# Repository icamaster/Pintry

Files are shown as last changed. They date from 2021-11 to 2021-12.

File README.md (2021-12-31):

## Introduction
The Pintry X2 is a two bay NAS (Network Attached Storage) based on the Raspberry Pi Compute Module 4. It uses the ASMedia AS1061 PCIe to Sata bridge to connect up to 2 drives (3.5'/2.5' HDD or 2.5' SSD) to the SoM running a Linux based OS (Raspberry Pi OS).

## Website
Here is a link for additional information: https://www.cezarchirila.com/projects/pintry-x2.html

## Features
* Supports both CM4 and CM4 lite variants
* 2 x SATA ports with power using ASM1061. It should work with both 2.5' and 3.5' HDDs/SSDs but so far it has only been tested with 2.5' SSDs (Western Digital WDS500G2B0A)
* On/Off switch - Can both wake up the CM4 or shut it down (see Device Tree Overlay section) 
* 2 x Fan headers (PWM pin connected, Tach pin unconnected)
* 12V Input Power (max 5A, required for 3.5' drives). 
* USB 2.0 Host port for connecting USB devices and a microUSB Device port for updating the eMMC on CM4. 
* Expander header for access to various GPIO

## Names have a meaning
Pi + Pantry = Pintry

## Device Tree Overlay
Add these changes at the end of the /boot/config.txt to enable specific functionality:
```
# Enable FAN control for FAN0
dtoverlay=gpio-fan,gpiopin=12

# Enable FAN control for FAN1
#dtoverlay=gpio-fan,gpiopin=13

# Enable full functionality of On/Off button
dtoverlay=gpio-shutdown,gpio_pin=21,active_low=0,gpio_pull=off

# Enable UART - UNTESTED
#dtoverlay=uart0,txd0_pin=14,rxd0_pin=15,pin_func=4
#enable_uart=1  
```
Remember to remove the '#' in from of options you want to enable. 

## Kernel
Previously, to be able to use SATA drives with a CM4 you had to recompile the kernel with added SATA support. See instructions [here](https://github.com/geerlingguy/raspberry-pi-pcie-devices/issues/1#issuecomment-717578358) (credit to [Jeff Geerling](github.com/geerlingguy) for instructions). However, newer kernel versions have SATA support built-in, so you should not have to worry about this.

## Enclosure
The enclosure supports 2.5' drives only. It does not have any mounting features for fans, but there is room for a 60mm fan on the bottom as shown in the images below. It does not need supports for printing. Designed in Fusion 360.

For assembly, you will need the following:
* 4 x M3 brass inserts (D0.46mm, L0.57mm)
* 4 x M3x18mm socket screws - for mounting the drives 
* 4 x M3x25mm socket screws - for mounting the drives
* 4 x M3x35mm socket screws - for joining the two halves of the enclosure

## Thermal management
To keep temperatures under control, I have used a RAM heatsink on the ASM1061 IC and a 60mm fan on the bottom of the enclosure tied to the FAN header and controlled via the 'gpio-fan' overlay. It is mounted in such way that it blows air over both the CM4 and the ASM1061.  

## Release
The current latest release is V1.1. This version has not been tested or manufactured yet, therefore I would suggest double checking it if you plan on bulding it!
All the necessary manufacturing and assembly files are in the 'OutputJob/Version' and 'Enclosure' folders.

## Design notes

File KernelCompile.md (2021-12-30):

# Credits to Jeff Geerling
These instructions have been pulled from https://github.com/geerlingguy

## Install dependencies
sudo apt install -y git bc bison flex libssl-dev make libncurses5-dev

## Clone source
git clone --depth=1 https://github.com/raspberrypi/linux

## Apply default configuration
cd linux
export KERNEL=kernel7l # use kernel8 for 64-bit, or kernel7l for 32-bit
make bcm2711_defconfig

## Customize the .config further with menuconfig
make menuconfig
 Enable the following:
 Device Drivers:
   -> Serial ATA and Parallel ATA drivers (libata)
     -> AHCI SATA support
     -> Marvell SATA support

 Alternatively add the following in .config manually:
 CONFIG_ATA=m
 CONFIG_ATA_VERBOSE_ERROR=y
 CONFIG_SATA_PMP=y
 CONFIG_SATA_AHCI=m
 CONFIG_SATA_MOBILE_LPM_POLICY=0
 CONFIG_ATA_SFF=y
 CONFIG_ATA_BMDMA=y
 CONFIG_SATA_MV=m

nano .config
 (edit CONFIG_LOCALVERSION and add a suffix that helps you identify your build)

## Build the kernel and copy everything into place
make -j4 zImage modules dtbs # 'Image' on 64-bit
sudo make modules_install
sudo cp arch/arm/boot/dts/*.dtb /boot/
sudo cp arch/arm/boot/dts/overlays/*.dtb* /boot/overlays/
sudo cp arch/arm/boot/dts/overlays/README /boot/overlays/
sudo cp arch/arm/boot/zImage /boot/$KERNEL.img

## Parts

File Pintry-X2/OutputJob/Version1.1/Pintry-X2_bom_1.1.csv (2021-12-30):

Component | Description | References | Value | Quantity Per PCB | Manufacturer | Part Number | Voltage Rating | Type | fit_field
1 | Unpolarized capacitor, small symbol | C18 | 15pF | 1 |  |  | 50V | NPO
2 | Unpolarized capacitor, small symbol | C19 C20 C45 C46 C47 C48 C51 C52 C53 C54 | 0.01uF | 10 |  |  | 25V | X7R
3 | Unpolarized capacitor, small symbol | C2 C3 C4 C7 C9 C11 C12 C13 C15 C23 C27 C28 C30 C31 C32 C33 C34 C35 C36 C37 C38 C39 C40 C41 C42 C43 C44 C57 C60 C65 | 0.1uF | 30 |  |  | 25V | X7R
4 | Unpolarized capacitor, small symbol | C61 | 1uF | 1 |  |  | 25V | X7R
5 | Unpolarized capacitor, small symbol | C1 C5 C14 C16 C17 C24 C29 C67 C68 | 10uF | 9 |  |  | 10V | X7R
6 | Unpolarized capacitor, small symbol | C58 | 22uF | 1 | Samsung | CL21A226MOQNNNE | 16V | X7R
7 | Unpolarized capacitor, small symbol | C6 C62 C63 C64 | 22uF | 4 | Murata | GRM21BR61A226ME51L | 16V | X7R
8 | Polarized capacitor, small symbol | C8 C10 C49 C50 C55 C56 C66 | 865080443007 | 7 | Wurth | 865080443007
9 | Unpolarized capacitor, small symbol | C59 | TBD | 1 |  |  | 25V | X7R | dnf
10 | LED Orange Clear | D9 D17 | APA2107SECK | 2 | Kingbright | APA2107SECK/J4-PRV
11 | LED Orange Clear | D8 | APA2107SECK | 1 | Kingbright | APA2107SECK/J4-PRV
12 | 300mW Zener Diode, SOD-323 | D24 D26 | BZX384-B13 | 2 | Nexperia | BZX384-B13,115
13 | Diode TVS 3V3 | D3 D4 D5 D6 D10 D11 D12 | D3V3M1U259-7 | 7 | Diodes | D3V3M1U2S9-7
14 | Diode | D13 D14 D21 D23 D25 | DF2S16FS,L3M | 5 | Toshiba | DF2S16FS,L3M
15 | Diode | D1 D2 D7 D15 D16 D20 D22 | DF2S6.2FS,L3M | 7 | Toshiba | DF2S6.2FS,L3M
16 | Ferrite bead, small symbol | FB1 FB2 FB3 FB4 FB5 FB6 | MPZ1608S101ATAH0 | 6 | TDK | MPZ1608S101ATAH0
17 | Common mode choke, 300mA, 300VAC, 22mH, 1.3 ohm, RN-102 | FL1 | DLW5BTM101SQ2L | 1 | Murata | DLW5BTM101SQ2L
18 | SATA Backplane Receptacle Vertical SMT | J9 J10 | 1735284-3 | 2 | TE Connectivity | 1735284-3
19 | DC Barrel Jack with an internal switch | J11 | 54-00131 | 1 | Tensility | 54-00131
20 | Micro SD Card Socket with card detection pins | J4 | DM3D-SF | 1 | Hirose | DM3D-SF
21 | Generic connector, double row, 02x05, odd/even pin numbering scheme (row 1 odd numbers, row 2 even numbers), script generated (kicad-library-utils/schlib/autogen/connector/) | J6 | Expansion | 1 | Adam Tech | 2PH2-10-UA
22 | Generic connector, single row, 01x04, script generated (kicad-library-utils/schlib/autogen/connector/) | J7 J8 | Fan | 2 | Molex | 47053-1000
23 | LAN Transformer Jack, RJ45, 10/100/1000 BaseT | J3 | JD0-0001NL | 1 | Pulse | JD0-0001NL
24 | Generic connector, single row, 01x03, script generated (kicad-library-utils/schlib/autogen/connector/) | J5 | UART | 1 | Adam Tech | PH1-03-UA
25 | USB Type A connector | J2 | USB_A | 1 | Amphenol ICC | 73725-11A0BLF
26 | USB Micro Type B connector | J1 | USB_B_Micro | 1 | Amphenol ICC | 10103594-0001LF
27 | 4.7µH Shielded Wirewound Inductor 2.6A 35mOhm | L1 | NRS5030T4R7MMGJ | 1 | Taiyo Yuden | NRS5030T4R7MMGJ
28 | 1.2µH Shielded Molded Inductor 10A 12mOhm | L2 | PA4341.122NLT | 1 | Pulse | PA4341.122NLT
29 |  | Module1 | ComputeModule4-CM4 | 1 | Hirose | 2x DF40C-100DS-0.4V
30 | PNP transistor, base/emitter/collector | Q6 | BC857BW | 1 | Nexperia | BC857BW,135
31 | N-MOSFET transistor, gate/source/drain | Q1 Q2 Q3 | BSS138PW | 3 | Nexperia | BSS138PW,115
32 | -12A Id, -30V Vds, P-Channel MOSFET | Q5 | SIA483DJ | 1 | Vishay | SIA483DJ-T1-GE3
33 | -12A Id, -30V Vds, P-Channel MOSFET | Q7 | SIA483DJ | 1 | Vishay | SIA483DJ-T1-GE3
34 | Resistor, US symbol | R33 R34 | 0R | 2 |  |  |  |  | dnf
35 | Resistor, US symbol | R3 R4 | 470R | 2
36 | Resistor, US symbol | R1 R6 R14 R19 R20 | 1K | 5
37 | Resistor, US symbol | R2 R5 R7 R8 R11 R16 R17 R18 R21 R27 R28 R32 | 4K7 | 12 |  |  |  |  | dnf
38 | Resistor, US symbol | R12 R13 | 12K1 | 2
39 | Resistor, US symbol | R30 | 30K1 | 1
40 | Resistor, US symbol | R9 R10 R15 R22 R23 R24 R25 R26 R31 R35 R36 | 100K | 11 |  |  |  |  | dnf
41 | Resistor, US symbol | R29 | 221K | 1
42 | Push button switch, generic, two pins | SW1 | SW_Push | 1 | TE Connectivity | 1-1825027-4
43 | Single Buffer Gate Tri-State, Low-Voltage CMOS | U4 | 74AHCT1G126 | 1 | Diodes | 74AHCT1G126SE-7
44 | 4.5V TO 18V INPUT, 6A SYNCHRONOUS BUCK CONVERTER | U13 | AP62600 | 1 | Diodes | AP62600SJ-7
45 | PCI Express 2.0 to 2 x SATA 6Gbps Controller | U7 | ASM1061 | 1 | ASMedia | ASM1061
46 | USB Switch IC 1 Channel 10-MSOP | U14 | FSUSB30MUX | 1 | ON Semiconductor | FSUSB30MUX
47 |  | U15 | MIC2005-0.5LYM5 | 1 | Microchip | MIC2005-0.5LYM5
48 | Single Schmitt Buffer Gate, Low-Voltage CMOS | U3 | SN74LVC1G17 | 1 | Texas Instruments | SN74LVC1G17DBVR
49 | 8-Mbit, 2.7 to 3.6V, SPI Flash Memory, SOIC-8 | U10 | SST25VF512A | 1 | Microchip | SST25VF512A-33-4I-SAE-T
50 | 4-Channel ESD Protection for Super-Speed USB 3.0 Interface, USON-10 | U1 U2 U5 U6 U11 U12 | TPD4EUSB30 | 6 | Texas Instruments | TPD4EUSB30DQAR
51 | Four pin crystal, GND on pins 2 and 4 | Y1 | ECS-200-12-33-AGN-TR | 1 | ECS | ECS-200-12-33-AGN-TR
Component Groups: | 51
Component Count: | 166
Fitted Components: | 166
Number of PCBs: | 1
Total components: | 166
Schematic Version: | 1.1
Schematic Date:
PCB Variant: | default
BoM Date: | 30/12/2021 15:42:43
Schematic Source: | Pintry-X2.kicad_sch
KiCad Version: | Eeschema (6.0.0)

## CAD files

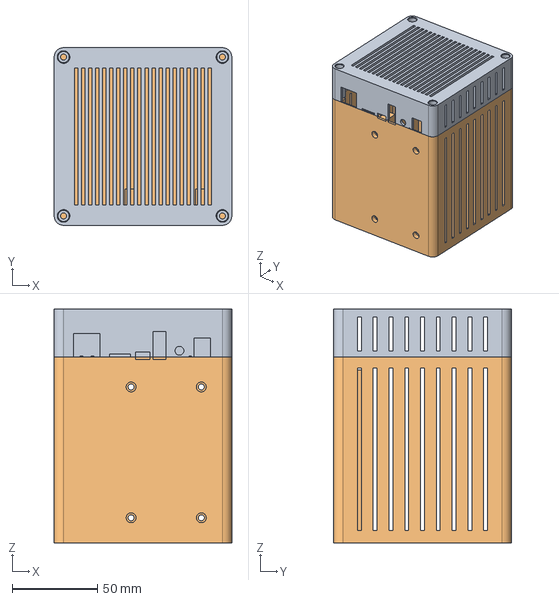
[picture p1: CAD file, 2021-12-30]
Pintry-X2/Enclosure/Pintry-X2_enclosure.step
104.0 x 104.0 x 137.0 mm

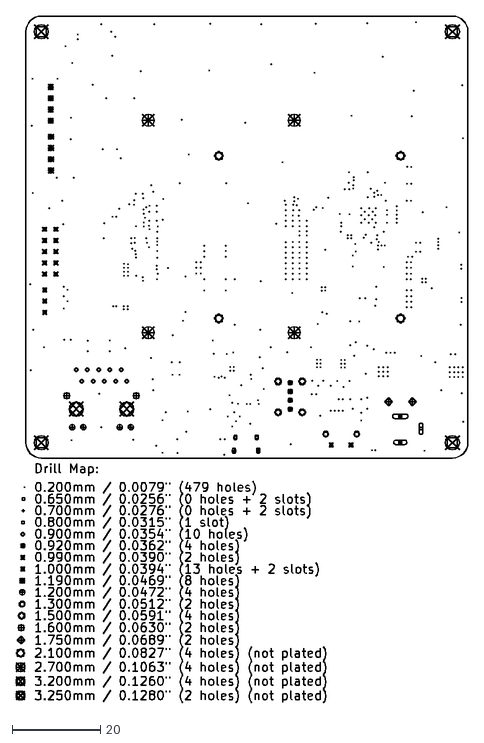
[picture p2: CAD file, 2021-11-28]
Pintry-X2/Pintry-X2-drl_map.dxf
102.2 x 155.4

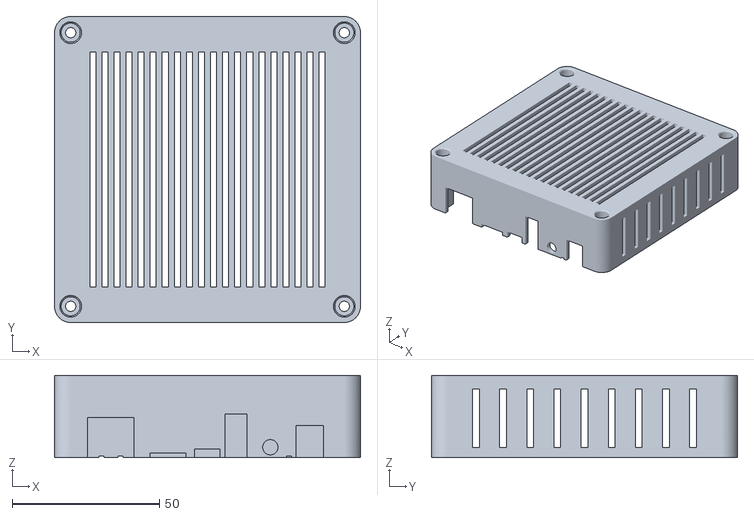
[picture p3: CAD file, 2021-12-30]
Pintry-X2/Enclosure/Bottom.stl
104.0 x 104.0 x 28.0

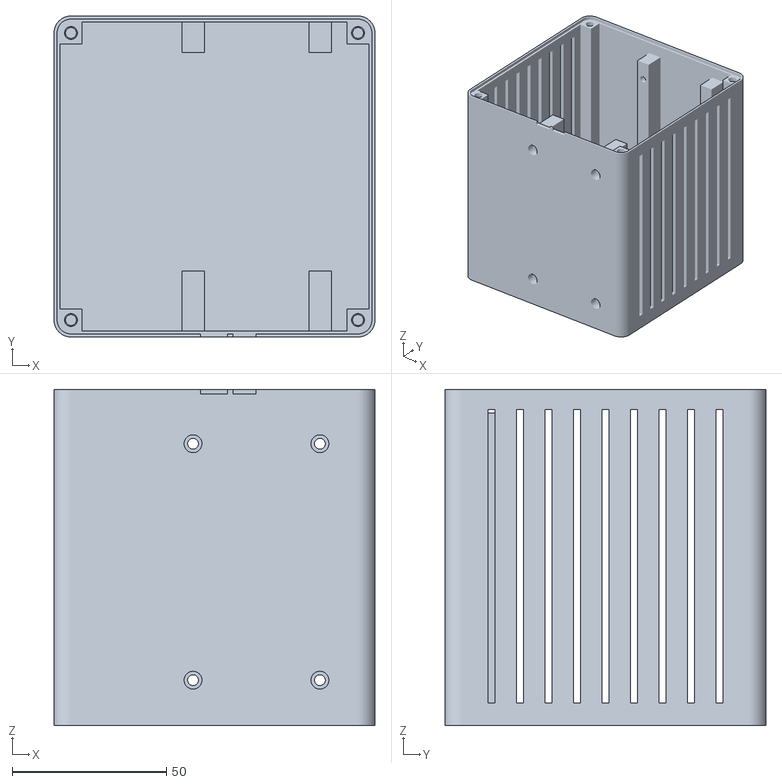
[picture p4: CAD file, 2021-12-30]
Pintry-X2/Enclosure/Top.stl
104.0 x 104.0 x 109.0

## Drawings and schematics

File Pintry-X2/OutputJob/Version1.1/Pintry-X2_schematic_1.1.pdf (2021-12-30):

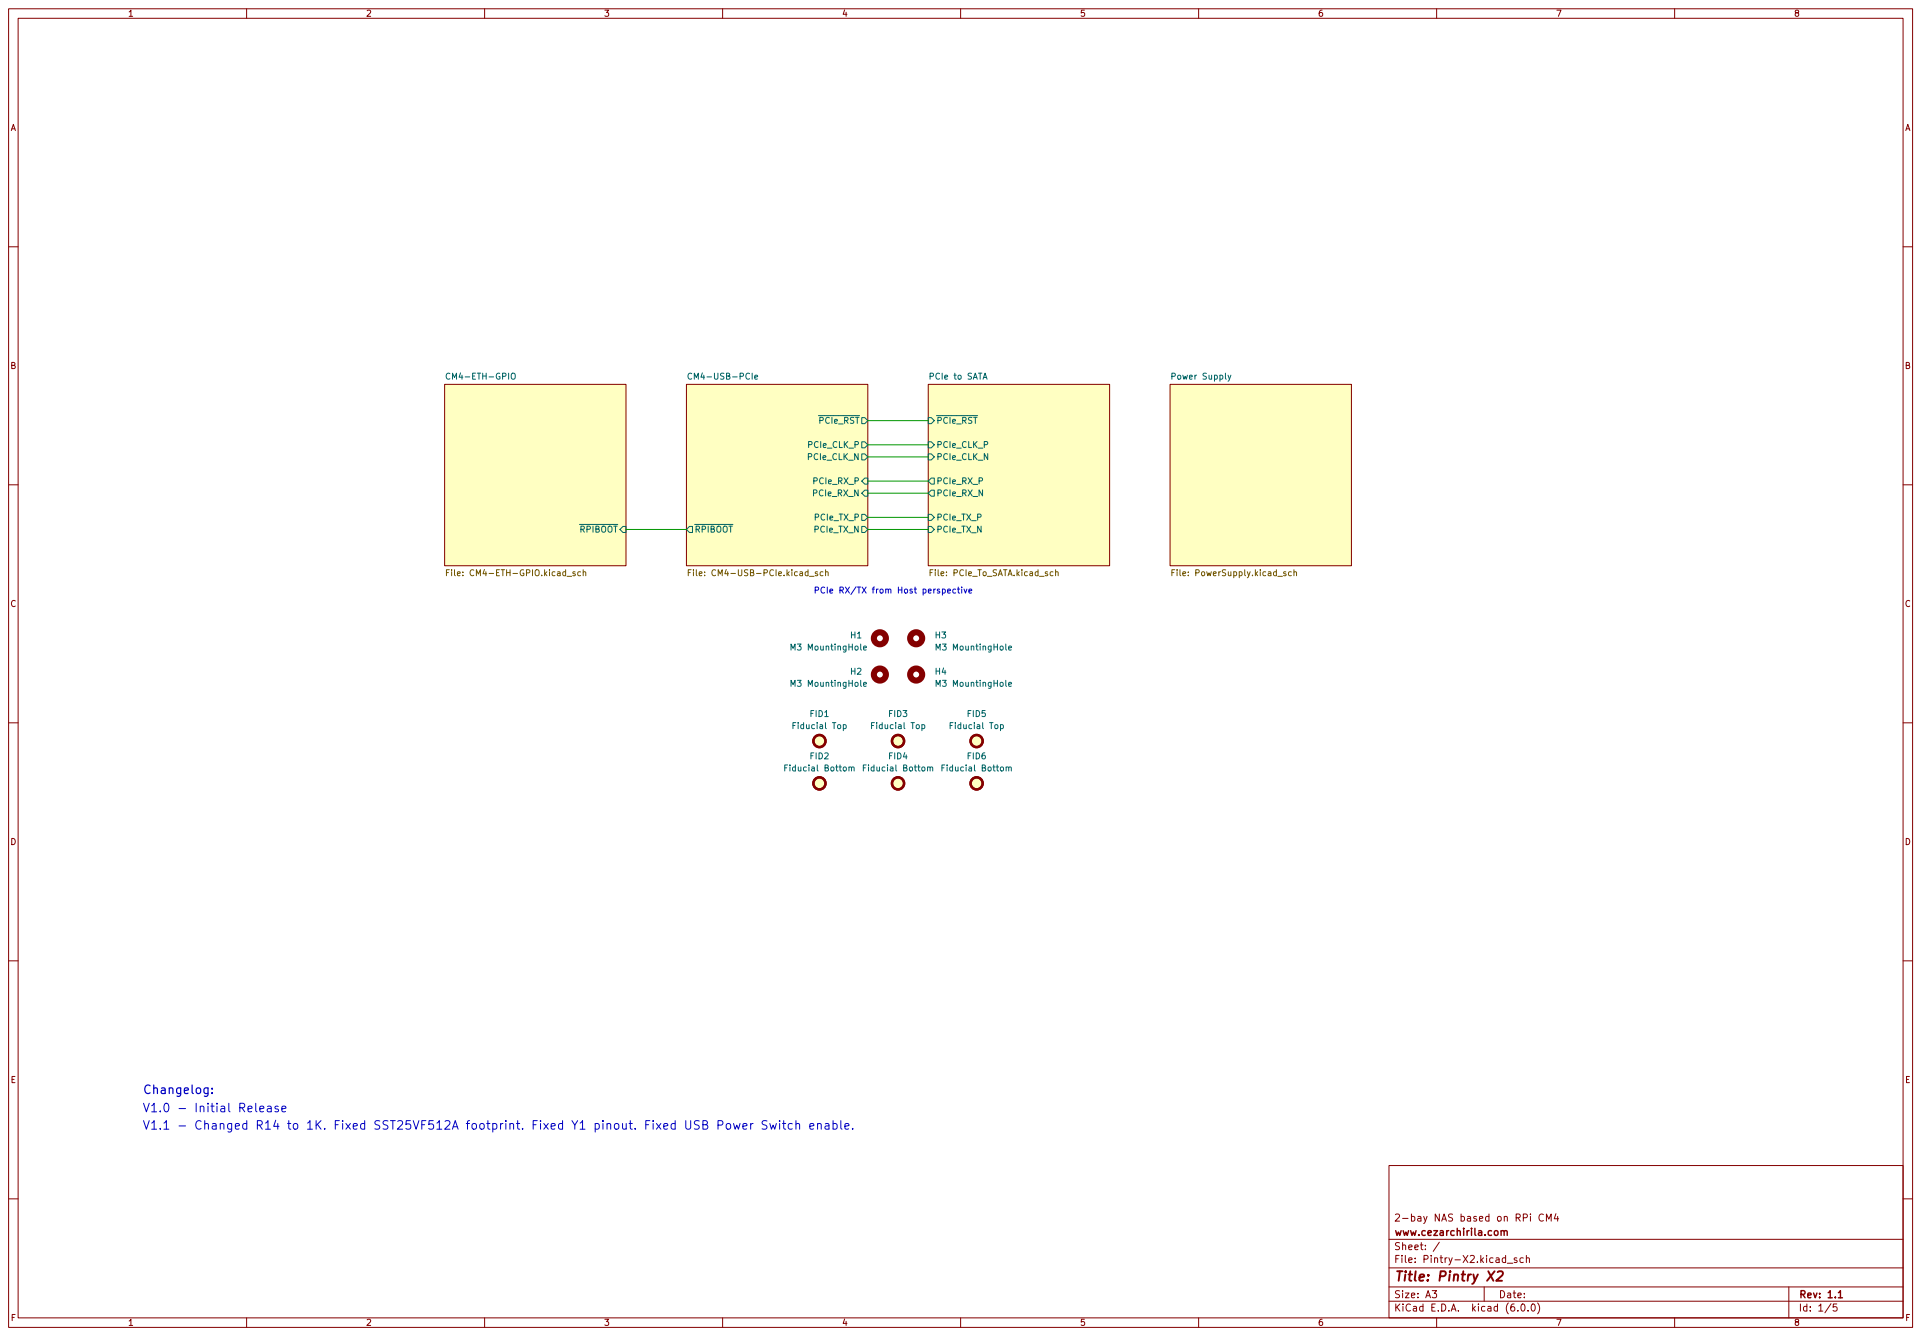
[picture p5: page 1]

File: PCIe_To_SATA.kicad_sch ~{RPIBOOT} CM4-ETH-GPIO

PCIe_TX_P
H3M3 MountingHole H4M3 MountingHole FID6 Fiducial Bottom

PCIe RX/TX from Host perspective

FID5 Fiducial Top FID4 Fiducial Bottom

Changelog:
V1.0 - Initial Release
V1.1 - Changed R14 to 1K. Fixed SST25VF512A footprint. Fixed Y1 pinout. Fixed USB Power Switch enable.

2-bay NAS based on RPi CM4
File: Pintry-X2.kicad_sch Sheet: / www.cezarchirila.com

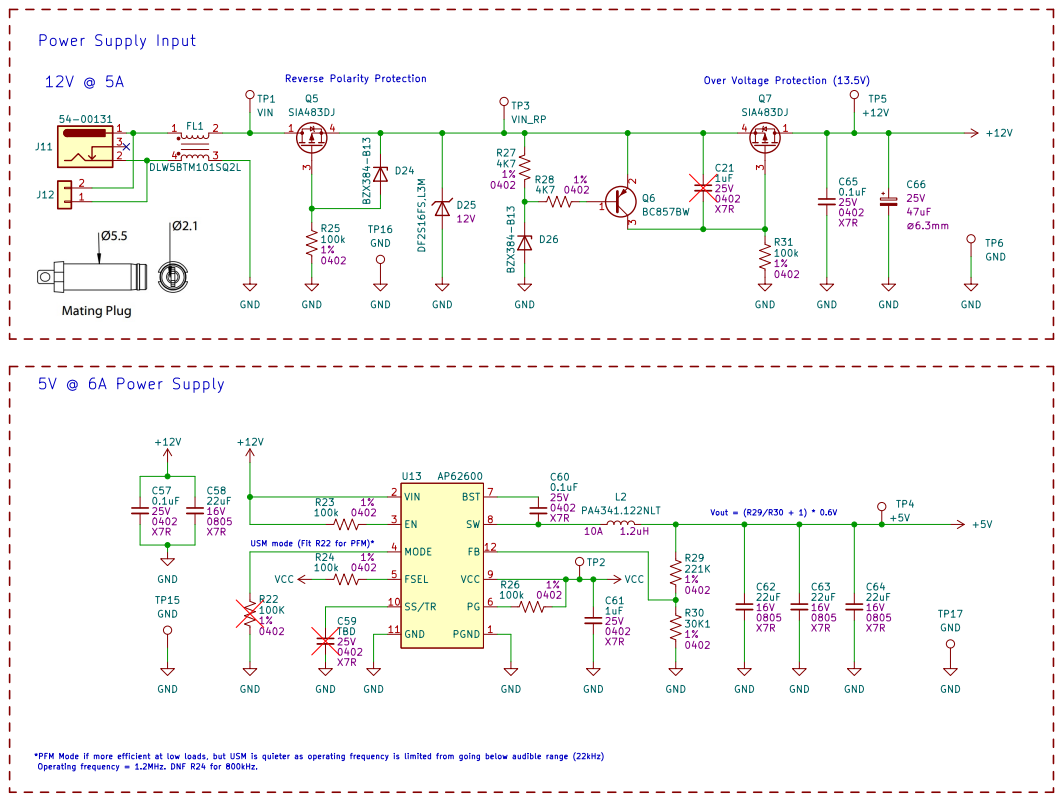
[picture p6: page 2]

*PFM Mode if more efficient at low loads, but USM is quieter as operating frequency is limited from going below audible range (22kHz) Operating frequency = 1.2MHz. DNF R24 for 800kHz.

2-bay NAS based on RPi CM4
Sheet: /Power Supply/ www.cezarchirila.com

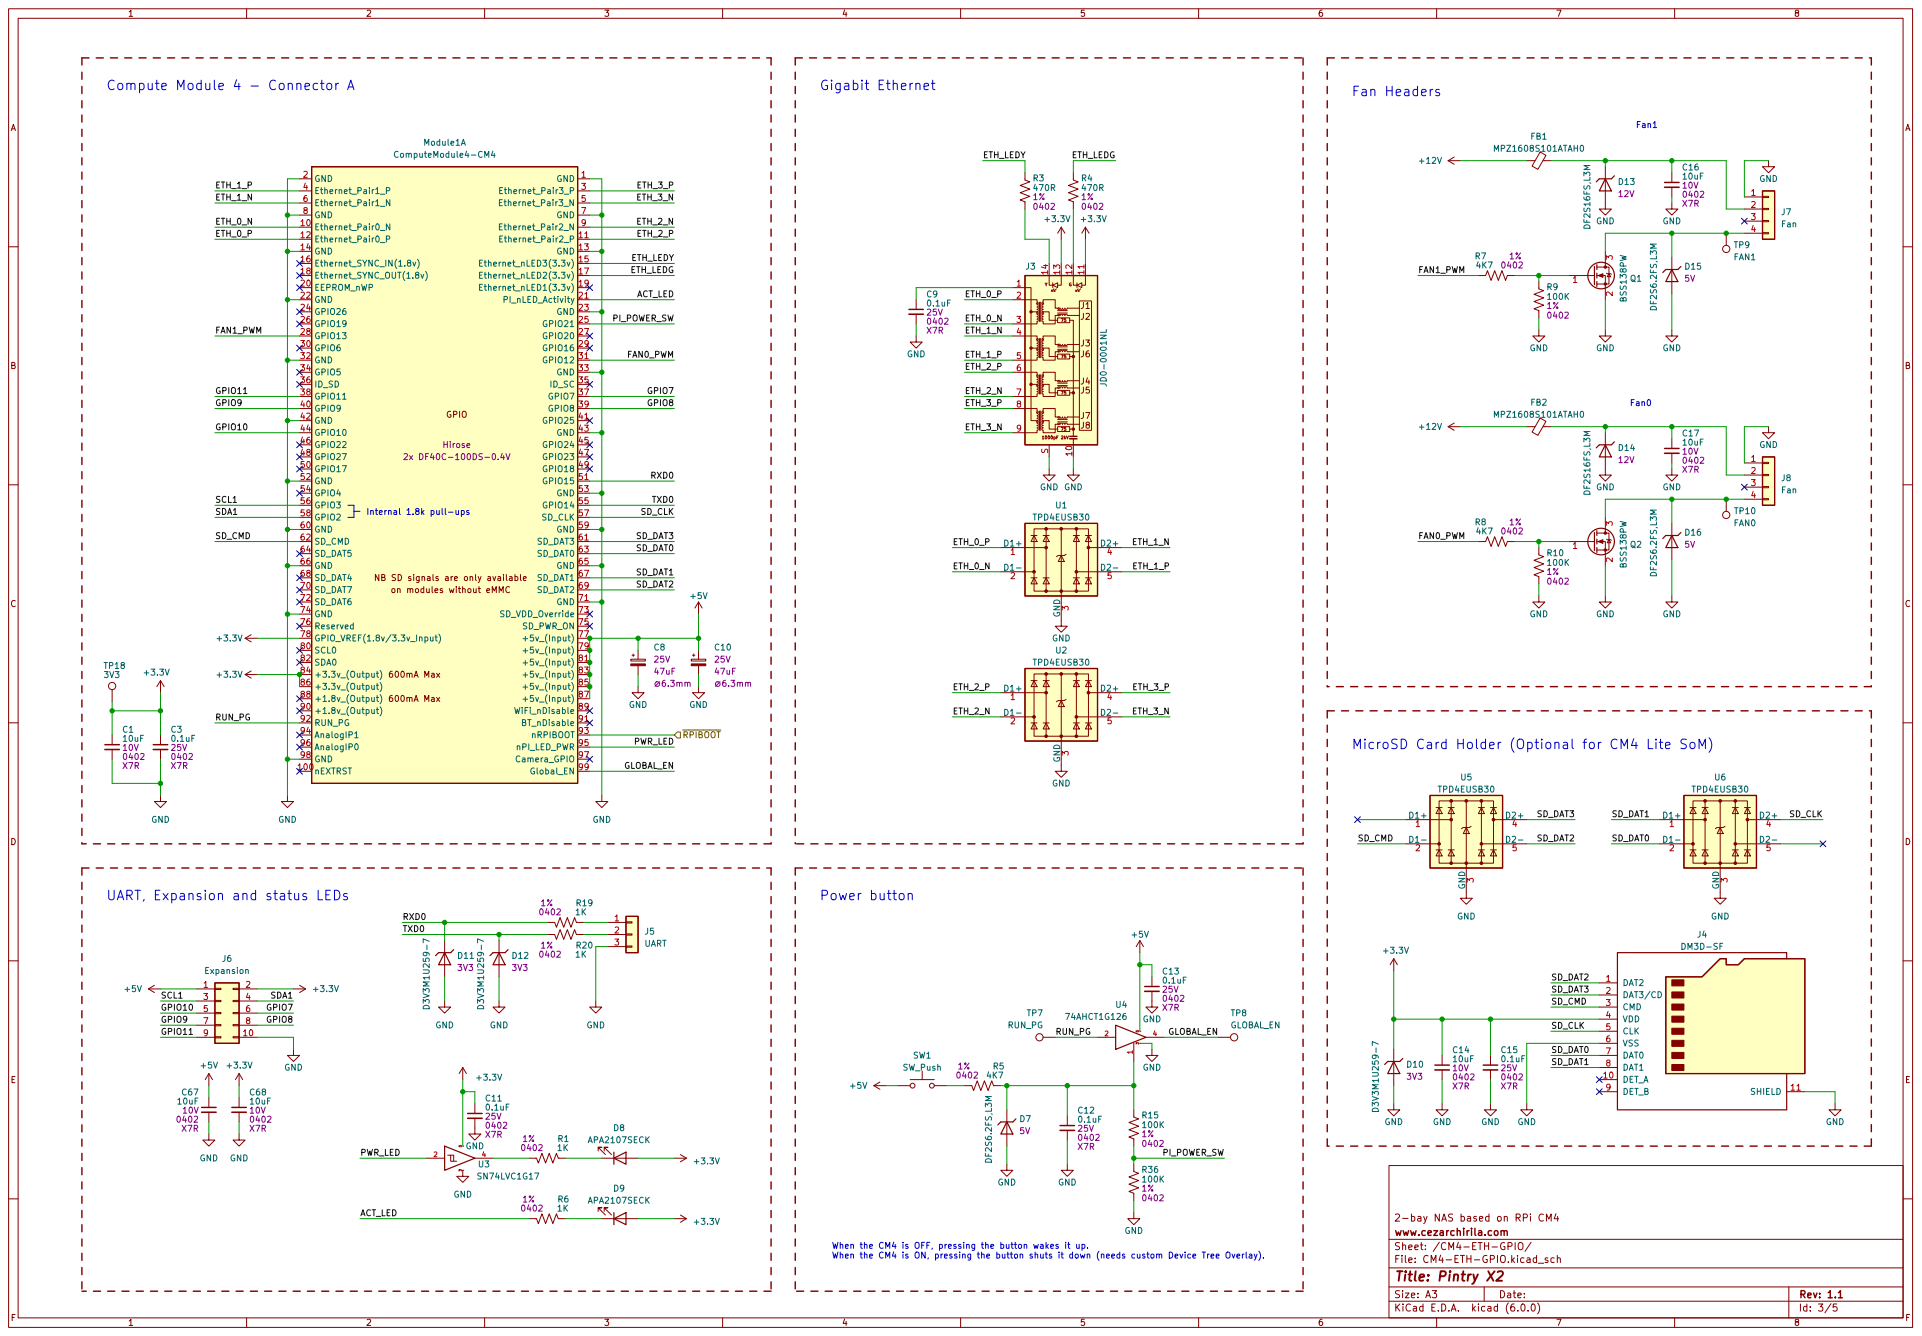
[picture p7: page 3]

600mA Max 600mA Max NB SD signals are only available

UART, Expansion and status LEDs
J6 Expansion +3.3VC68

2-bay NAS based on RPi CM4 R5

File: CM4-ETH-GPIO.kicad_sch Sheet: /CM4-ETH-GPIO/ www.cezarchirila.com

When the CM4 is OFF, pressing the button wakes it up.
When the CM4 is ON, pressing the button shuts it down (needs custom Device Tree Overlay).

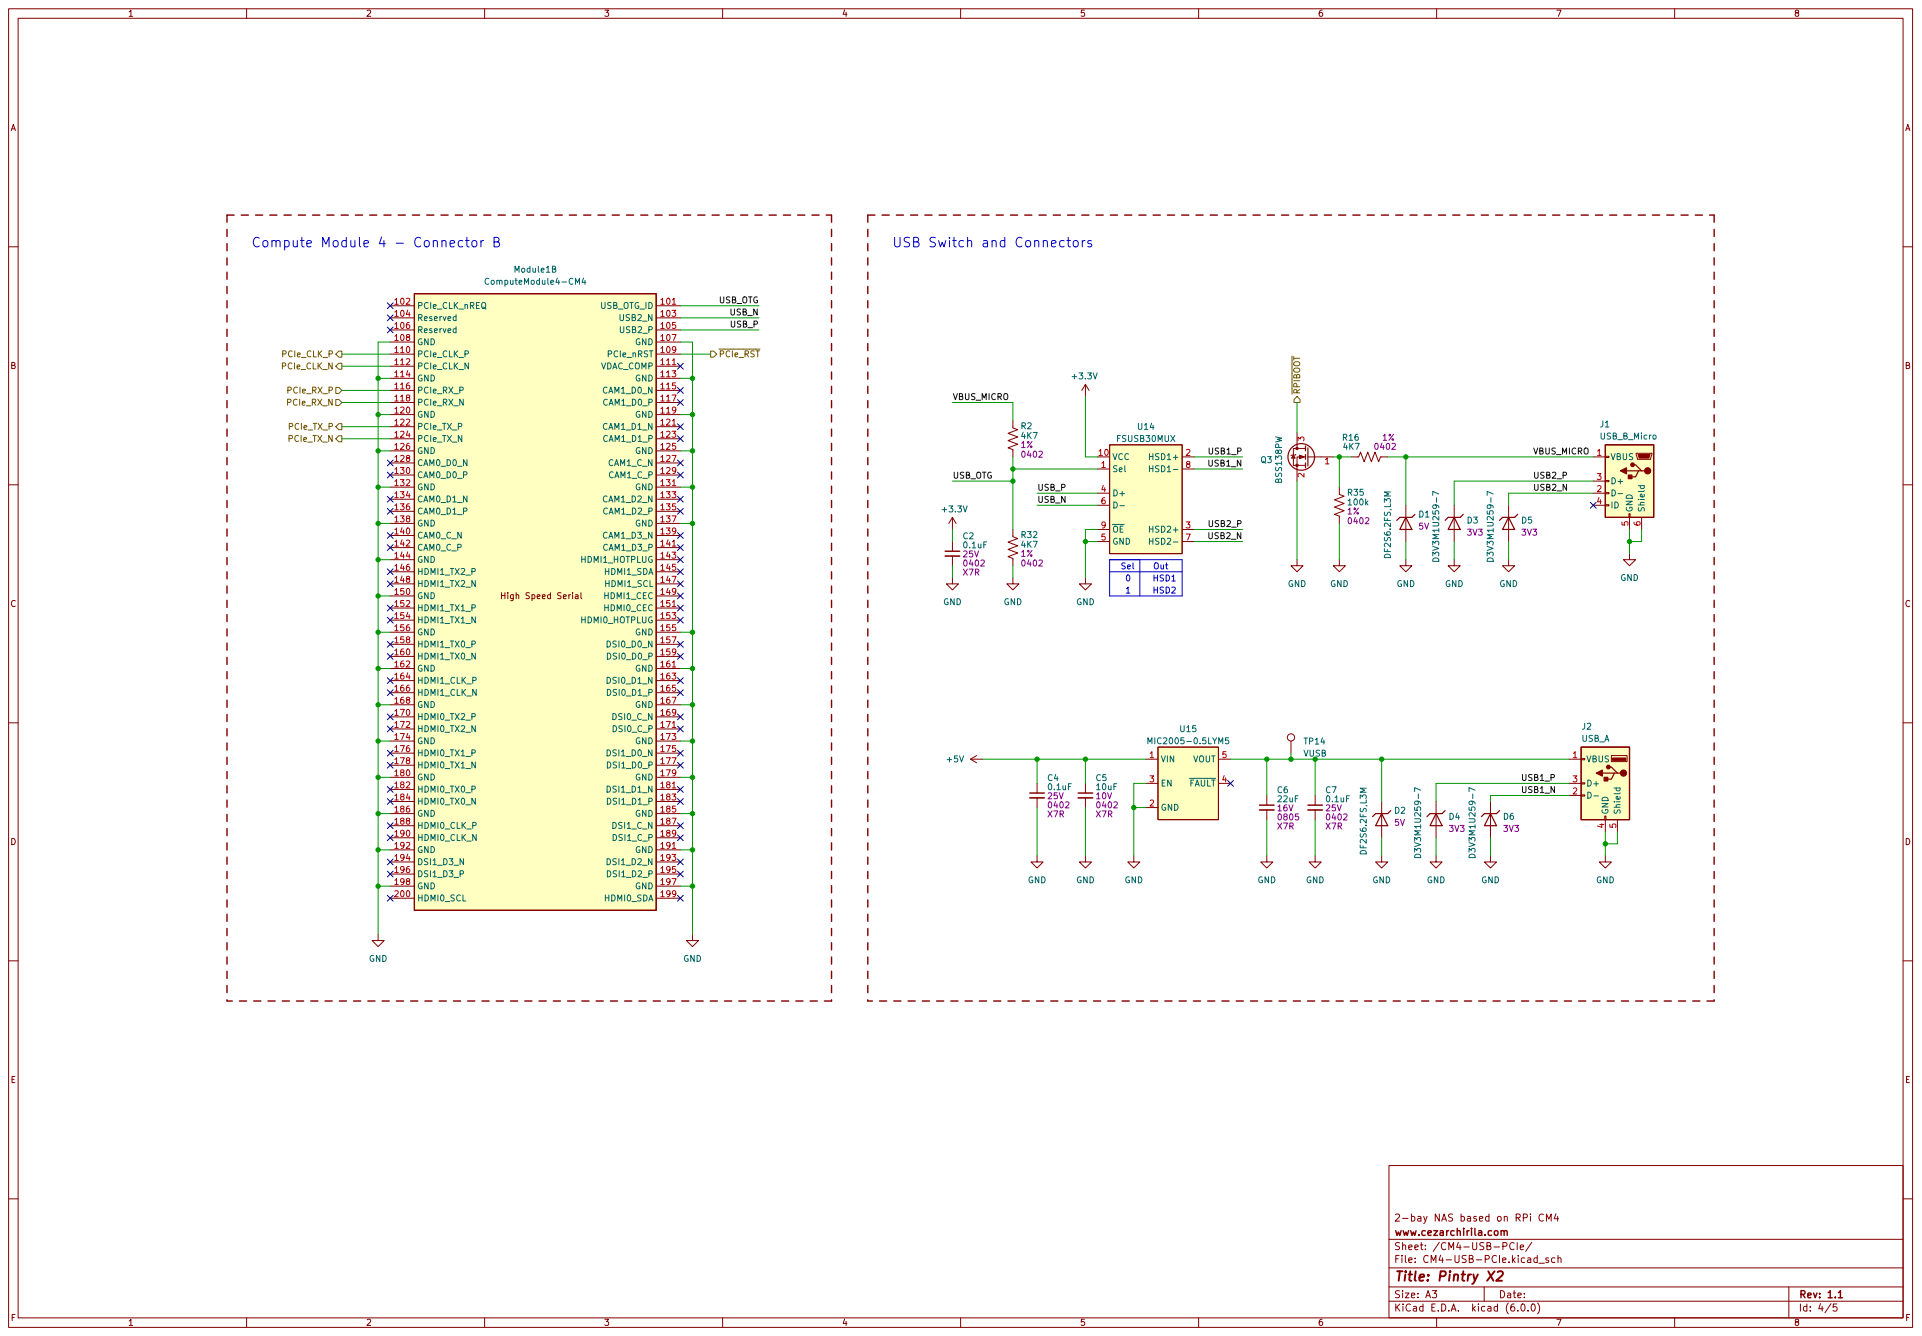
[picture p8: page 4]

USB1_P USB Switch and Connectors

2-bay NAS based on RPi CM4 GND

File: CM4-USB-PCIe.kicad_sch Sheet: /CM4-USB-PCIe/ www.cezarchirila.com

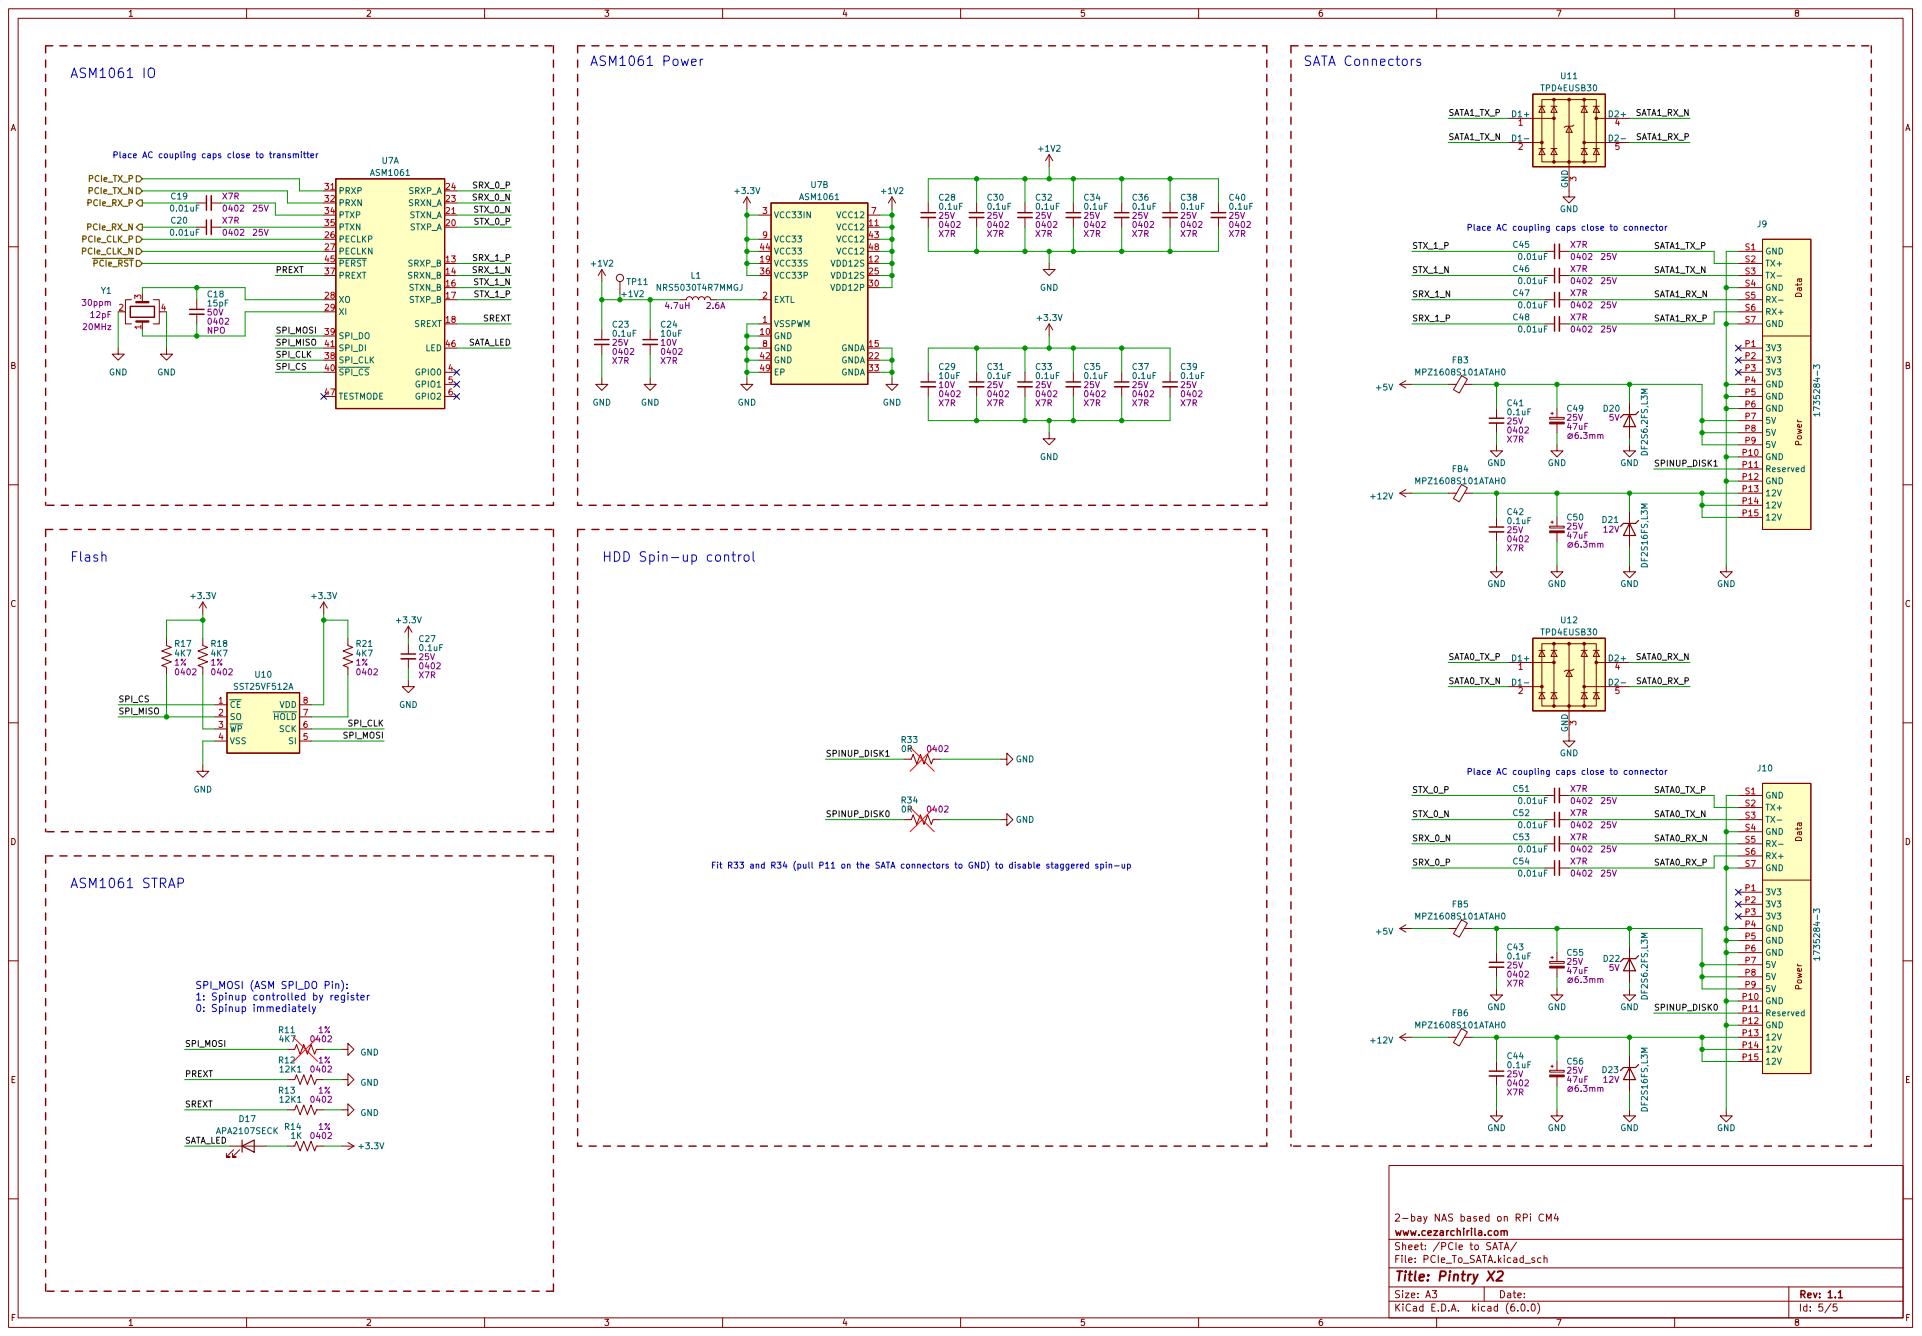
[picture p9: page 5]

Place AC coupling caps close to transmitter

Place AC coupling caps close to connector

HDD Spin-up control

Fit R33 and R34 (pull P11 on the SATA connectors to GND) to disable staggered spin-up

SPI_MOSI (ASM SPI_DO Pin):
1: Spinup controlled by register
0: Spinup immediately
SPINUP_DISK0 SREXT
PREXT SPI_MOSI SATA_LED

2-bay NAS based on RPi CM4
File: PCIe_To_SATA.kicad_sch Sheet: /PCIe to SATA/ www.cezarchirila.com

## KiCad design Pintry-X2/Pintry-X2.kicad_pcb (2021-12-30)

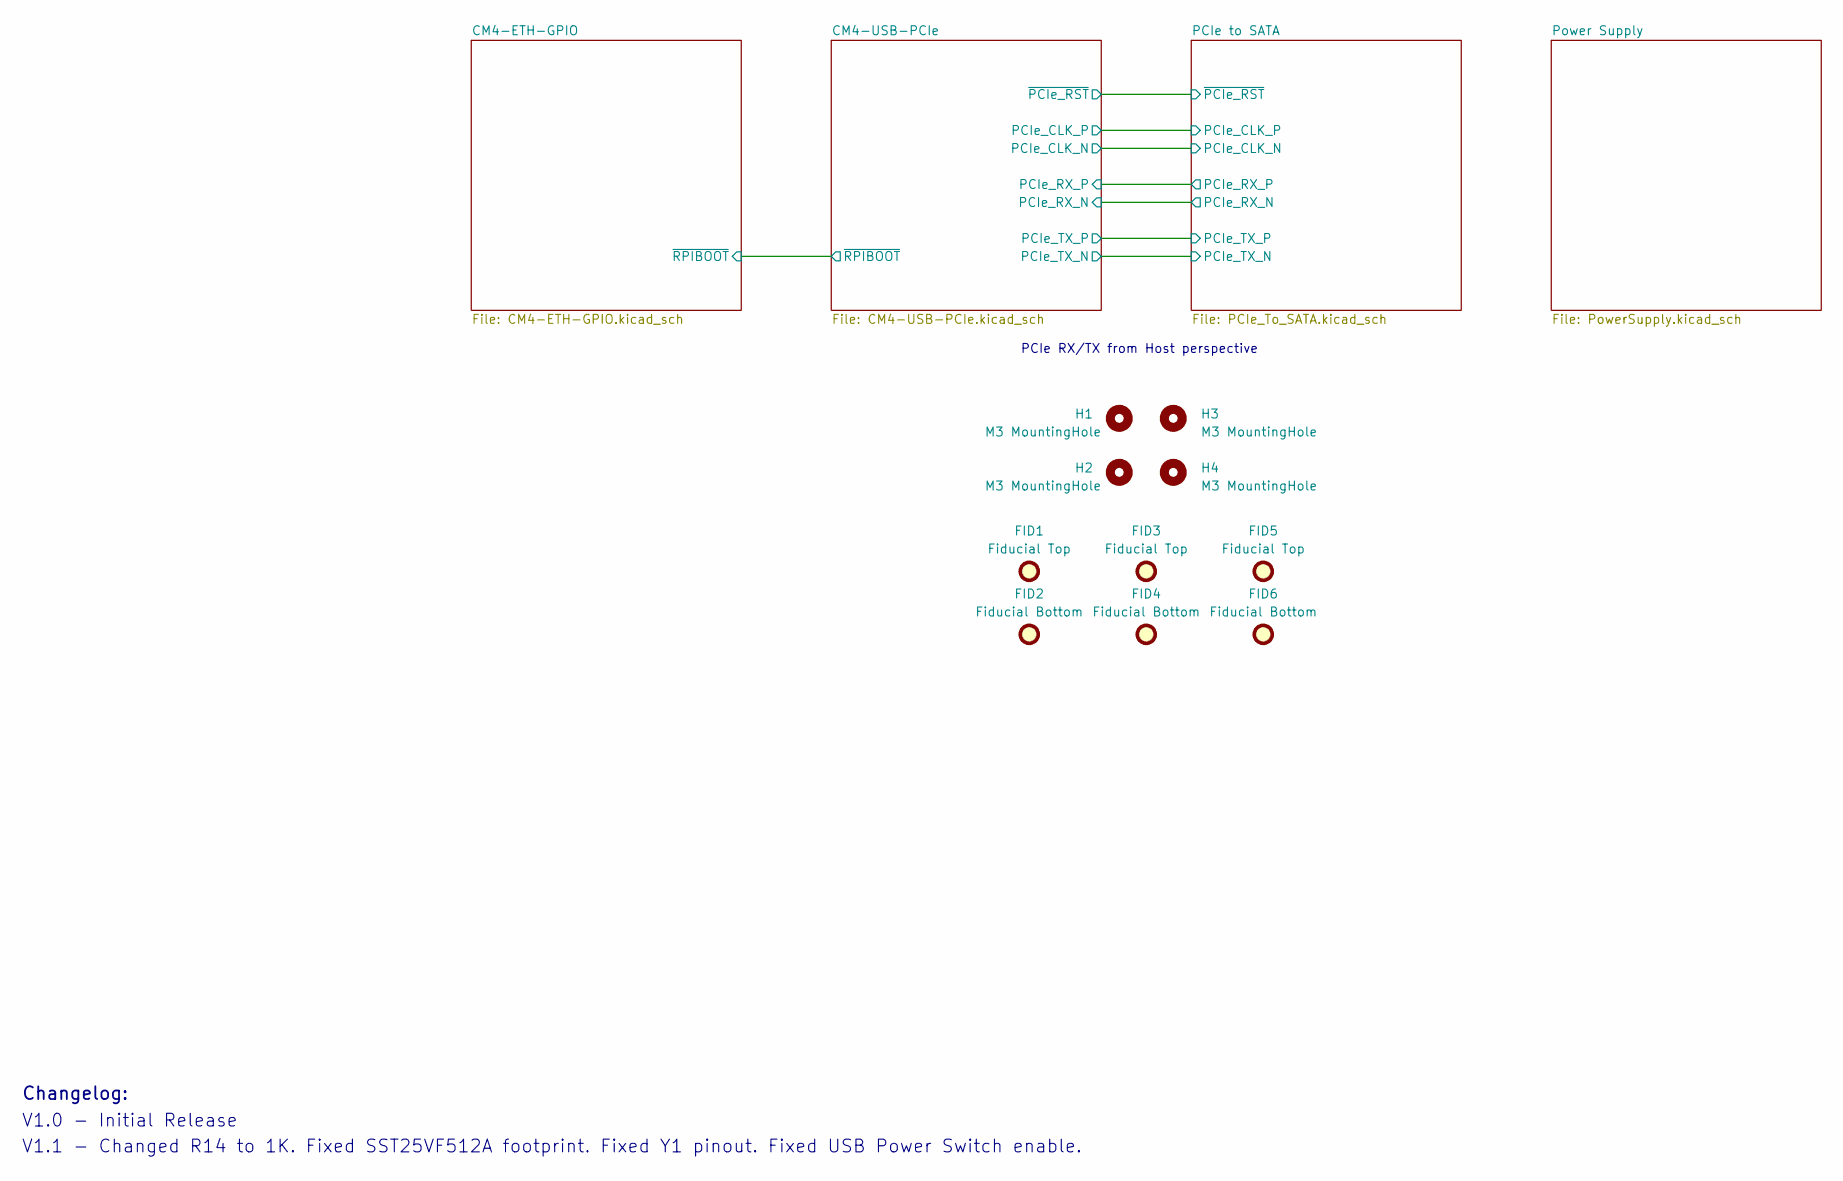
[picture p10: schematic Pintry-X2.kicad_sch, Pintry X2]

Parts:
FID1, FID3, FID5: Fiducial Top; Fiducial_1mm_Mask2mm
FID2, FID4, FID6: Fiducial Bottom; Fiducial_1mm_Mask2mm
H1, H2, H3, H4: M3 MountingHole; MountingHole_3.2mm_M3

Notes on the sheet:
V1.0 - Initial Release
Changelog:
PCIe RX/TX from Host perspective
V1.1 - Changed R14 to 1K. Fixed SST25VF512A footprint. Fixed Y1 pinout. Fixed USB Power Switch enable.

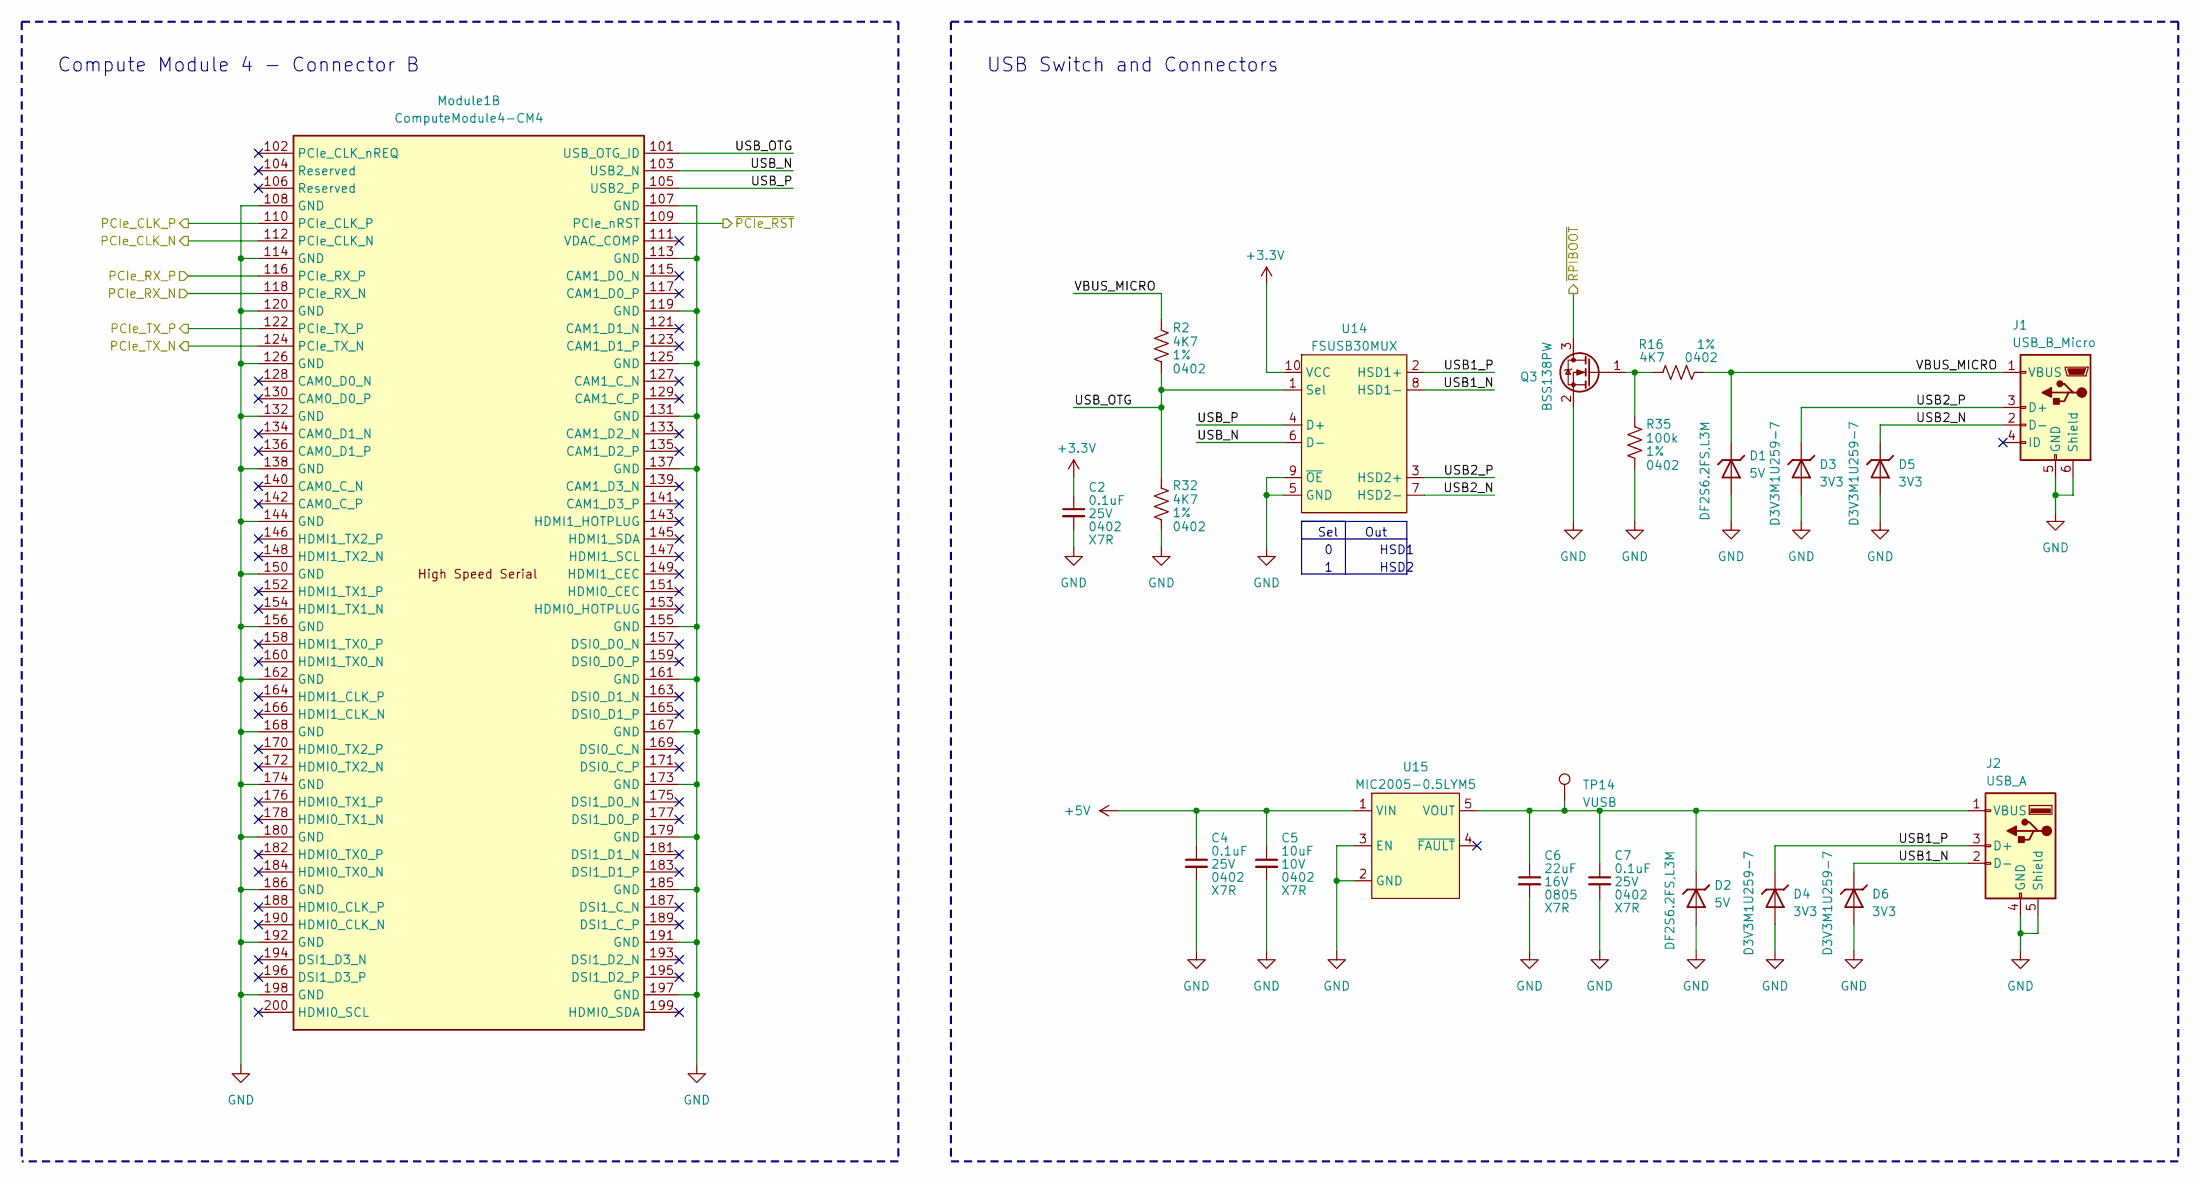
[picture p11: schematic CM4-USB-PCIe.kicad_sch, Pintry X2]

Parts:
C2, C4, C7: 0.1uF; C_0402_1005Metric; Voltage Rating 25V
C5: 10uF; C_0402_1005Metric; Voltage Rating 10V
C6: 22uF; C_0805_2012Metric; Voltage Rating 16V; Part Number GRM21BR61A226ME51L
D1, D2: DF2S6.2FS,L3M; D_SOD-923; Part Number DF2S6.2FS,L3M
D3, D4, D5, D6: D3V3M1U259-7; D_SOD-923; Part Number D3V3M1U2S9-7
J1: USB_B_Micro; USB_Micro-B_Amphenol_10103594-0001LF_Horizontal; Part Number 10103594-0001LF
J2: USB_A; USB_A_Amphenol_ICC_73725-11A0BLF_Horizontal; Part Number 73725-11A0BLF
Module1: ComputeModule4-CM4; Raspberry-Pi-4-Compute-Module; Part Number 2x DF40C-100DS-0.4V
Q3: BSS138PW; SOT-323_SC-70; Part Number BSS138PW,115
R2, R16, R32: 4K7; R_0402_1005Metric; Tolerance 1%
R35: 100k; R_0402_1005Metric; Tolerance 1%
TP14: VUSB; TestPoint_Pad_D1.0mm
U14: FSUSB30MUX; MSOP-10_3x3mm_P0.5mm; Part Number FSUSB30MUX
U15: MIC2005-0.5LYM5; SOT-23-5; Part Number MIC2005-0.5LYM5

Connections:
+3V3: C2.1, U14.10 (VCC); also elsewhere on the board
+5V: C4.1, C5.1, U15.1 (VIN); also elsewhere on the board
/CM4-ETH-GPIO/~RPIBOOT: Q3.3 (D); also elsewhere on the board
/CM4-USB-PCIe/PCIe_CLK_N: Module1.112 (PCIe_CLK_N); also elsewhere on the board
/CM4-USB-PCIe/PCIe_CLK_P: Module1.110 (PCIe_CLK_P); also elsewhere on the board
/CM4-USB-PCIe/PCIe_RX_N: Module1.118 (PCIe_RX_N); also elsewhere on the board
/CM4-USB-PCIe/PCIe_RX_P: Module1.116 (PCIe_RX_P); also elsewhere on the board
/CM4-USB-PCIe/PCIe_TX_N: Module1.124 (PCIe_TX_N); also elsewhere on the board
/CM4-USB-PCIe/PCIe_TX_P: Module1.122 (PCIe_TX_P); also elsewhere on the board
/CM4-USB-PCIe/USB1_N: D6.1 (K), J2.2 (D-), U14.8 (HSD1-)
/CM4-USB-PCIe/USB1_P: D4.1 (K), J2.3 (D+), U14.2 (HSD1+)
/CM4-USB-PCIe/USB2_N: D5.1 (K), J1.2 (D-), U14.7 (HSD2-)
/CM4-USB-PCIe/USB2_P: D3.1 (K), J1.3 (D+), U14.3 (HSD2+)
/CM4-USB-PCIe/USB_N: Module1.103 (USB2_N), U14.6 (D-)
/CM4-USB-PCIe/USB_OTG: Module1.101 (USB_OTG_ID), R2.2, R32.1, U14.1 (Sel)
/CM4-USB-PCIe/USB_P: Module1.105 (USB2_P), U14.4 (D+)
/CM4-USB-PCIe/VBUS_MICRO: D1.1 (K), J1.1 (VBUS), R2.1, R16.2
/CM4-USB-PCIe/~PCIe_RST: Module1.109 (PCIe_nRST); also elsewhere on the board
GND: C2.2, C4.2, C5.2, C6.2, C7.2, D1.2 (A), D2.2 (A), D3.2 (A), D4.2 (A), D5.2 (A), D6.2 (A), J1.5 (GND), J1.6 (Shield), J2.4 (GND), J2.5 (Shield), Module1.107 (GND), Module1.108 (GND), Module1.113 (GND), Module1.114 (GND), Module1.119 (GND), Module1.120 (GND), Module1.125 (GND), Module1.126 (GND), Module1.131 (GND), Module1.132 (GND), Module1.137 (GND), Module1.138 (GND), Module1.144 (GND), Module1.150 (GND), Module1.155 (GND), Module1.156 (GND), Module1.161 (GND), Module1.162 (GND), Module1.167 (GND), Module1.168 (GND), Module1.173 (GND), Module1.174 (GND), Module1.179 (GND), Module1.180 (GND), Module1.185 (GND), Module1.186 (GND), Module1.191 (GND), Module1.192 (GND), Module1.197 (GND), Module1.198 (GND), Q3.2 (S), R32.2, R35.2, U14.5 (GND), U14.9 (~OE), U15.2 (GND), U15.3 (EN); also elsewhere on the board
unnamed: C6.1, C7.1, D2.1 (K), J2.1 (VBUS), TP14.1, U15.5 (VOUT)
unnamed: Q3.1 (G), R16.1, R35.1

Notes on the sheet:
Compute Module 4 - Connector B
Sel Out
USB Switch and Connectors
1 HSD2
0 HSD1

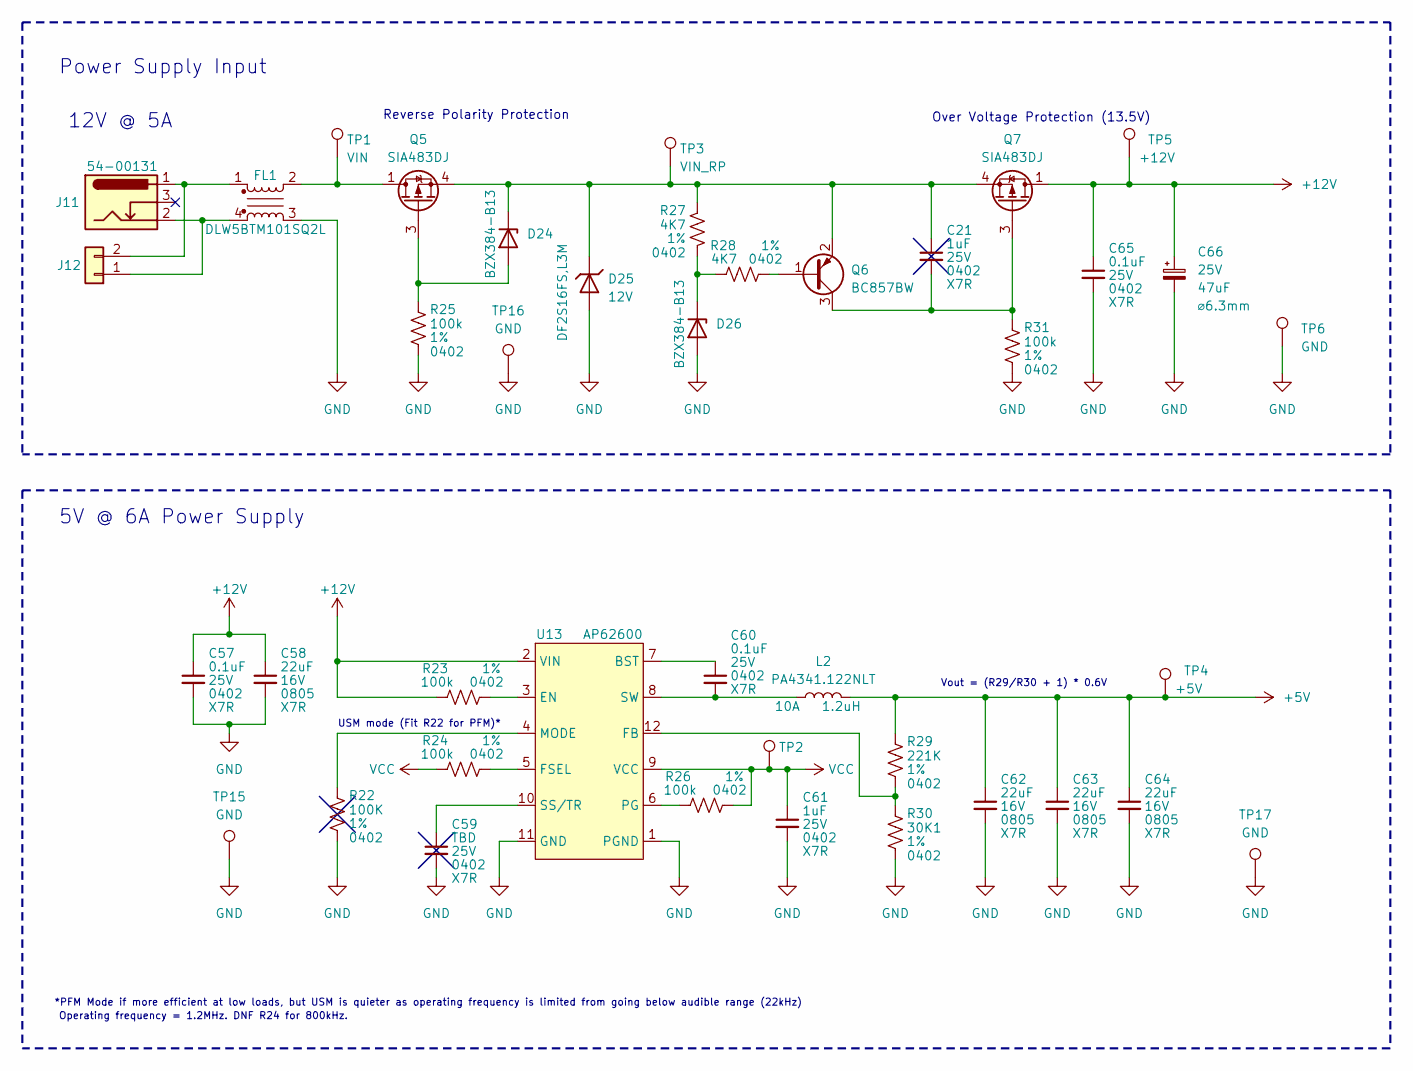
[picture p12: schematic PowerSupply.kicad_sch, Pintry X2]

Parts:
C21, C61: 1uF; C_0402_1005Metric; Voltage Rating 25V
C57, C60, C65: 0.1uF; C_0402_1005Metric; Voltage Rating 25V
C58: 22uF; C_0805_2012Metric; Voltage Rating 16V; Part Number CL21A226MOQNNNE
C59: TBD; C_0402_1005Metric; Voltage Rating 25V
C62, C63, C64: 22uF; C_0805_2012Metric; Voltage Rating 16V; Part Number GRM21BR61A226ME51L
C66: 865080443007; CP_Elec_6.3x5.4; Voltage 25V; Part Number 865080443007
D24, D26: BZX384-B13; D_SOD-323; Part Number BZX384-B13,115
D25: DF2S16FS,L3M; D_SOD-923; Part Number DF2S16FS,L3M
FL1: DLW5BTM101SQ2L; Part Number DLW5BTM101SQ2L
J11: 54-00131; Part Number 54-00131
J12: Alternate Power Connector; SolderWire-1sqmm_1x02_P5.4mm_D1.4mm_OD2.7mm
L2: PA4341.122NLT; Pulse_PA4341; Current Rating 10A; Part Number PA4341.122NLT
Q5, Q7: SIA483DJ; Vishay_PowerPAK_SC70-6L_Single; PartNumber SIA483DJ-T1-GE3
Q6: BC857BW; SOT-323_SC-70; Part Number BC857BW,135
R22: 100K; R_0402_1005Metric; Tolerance 1%
R23, R24, R25, R26, R31: 100k; R_0402_1005Metric; Tolerance 1%
R27, R28: 4K7; R_0402_1005Metric; Tolerance 1%
R29: 221K; R_0402_1005Metric; Tolerance 1%
R30: 30K1; R_0402_1005Metric; Tolerance 1%
TP1: VIN; TestPoint_Pad_D1.0mm
TP2: VCC; TestPoint_Pad_D1.0mm
TP3: VIN_RP; TestPoint_Pad_D1.0mm
TP4: +5V; TestPoint_Pad_D1.0mm
TP5: +12V; TestPoint_Pad_D1.0mm
TP6, TP15, TP16, TP17: GND; TestPoint_Pad_D1.0mm
U13: AP62600; V-QFN2030-12 (Type A); Part Number AP62600SJ-7

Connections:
+5V: C62.1, C63.1, C64.1, L2.2, R29.1, TP4.1; also elsewhere on the board
+12V: C57.1, C58.1, C65.1, C66.1, Q7.1 (D), R23.1, TP5.1, U13.2 (VIN); also elsewhere on the board
GND: C57.2, C58.2, C59.2, C61.2, C62.2, C63.2, C64.2, C65.2, C66.2, D25.2 (A), D26.2 (A), FL1.3, R22.2, R25.2, R30.2, R31.2, TP6.1, TP15.1, TP16.1, TP17.1, U13.1 (PGND), U13.11 (GND); also elsewhere on the board
unnamed: C21.1, D24.1 (K), D25.1 (K), Q5.4 (S), Q6.2 (E), Q7.4 (S), R27.1, TP3.1
unnamed: C21.2, Q6.3 (C), Q7.3 (G), R31.1
unnamed: C59.1, U13.10 (SS/TR)
unnamed: C60.1, U13.7 (BST)
unnamed: C60.2, L2.1, U13.8 (SW)
unnamed: D24.2 (A), Q5.3 (G), R25.1
unnamed: D26.1 (K), R27.2, R28.1
unnamed: FL1.1, J11.1 (A), J12.2
unnamed: FL1.2, Q5.1 (D), TP1.1
unnamed: FL1.4, J11.2 (B), J12.1
unnamed: Q6.1 (B), R28.2
unnamed: R22.1, U13.4 (MODE)
unnamed: R23.2, U13.3 (EN)
unnamed: R24.2, U13.5 (FSEL)
unnamed: R26.1, U13.6 (PG)
unnamed: R29.2, R30.1, U13.12 (FB)
VCC: C61.1, R24.1, R26.2, TP2.1, U13.9 (VCC)

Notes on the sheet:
5V @ 6A Power Supply
Power Supply Input
12V @ 5A
USM mode (Fit R22 for PFM)*
Vout = (R29/R30 + 1) * 0.6V
Operating frequency = 1.2MHz. DNF R24 for 800kHz.
*PFM Mode if more efficient at low loads, but USM is quieter as operating frequency is limited from going below audible range (22kHz)
Reverse Polarity Protection
Over Voltage Protection (13.5V)

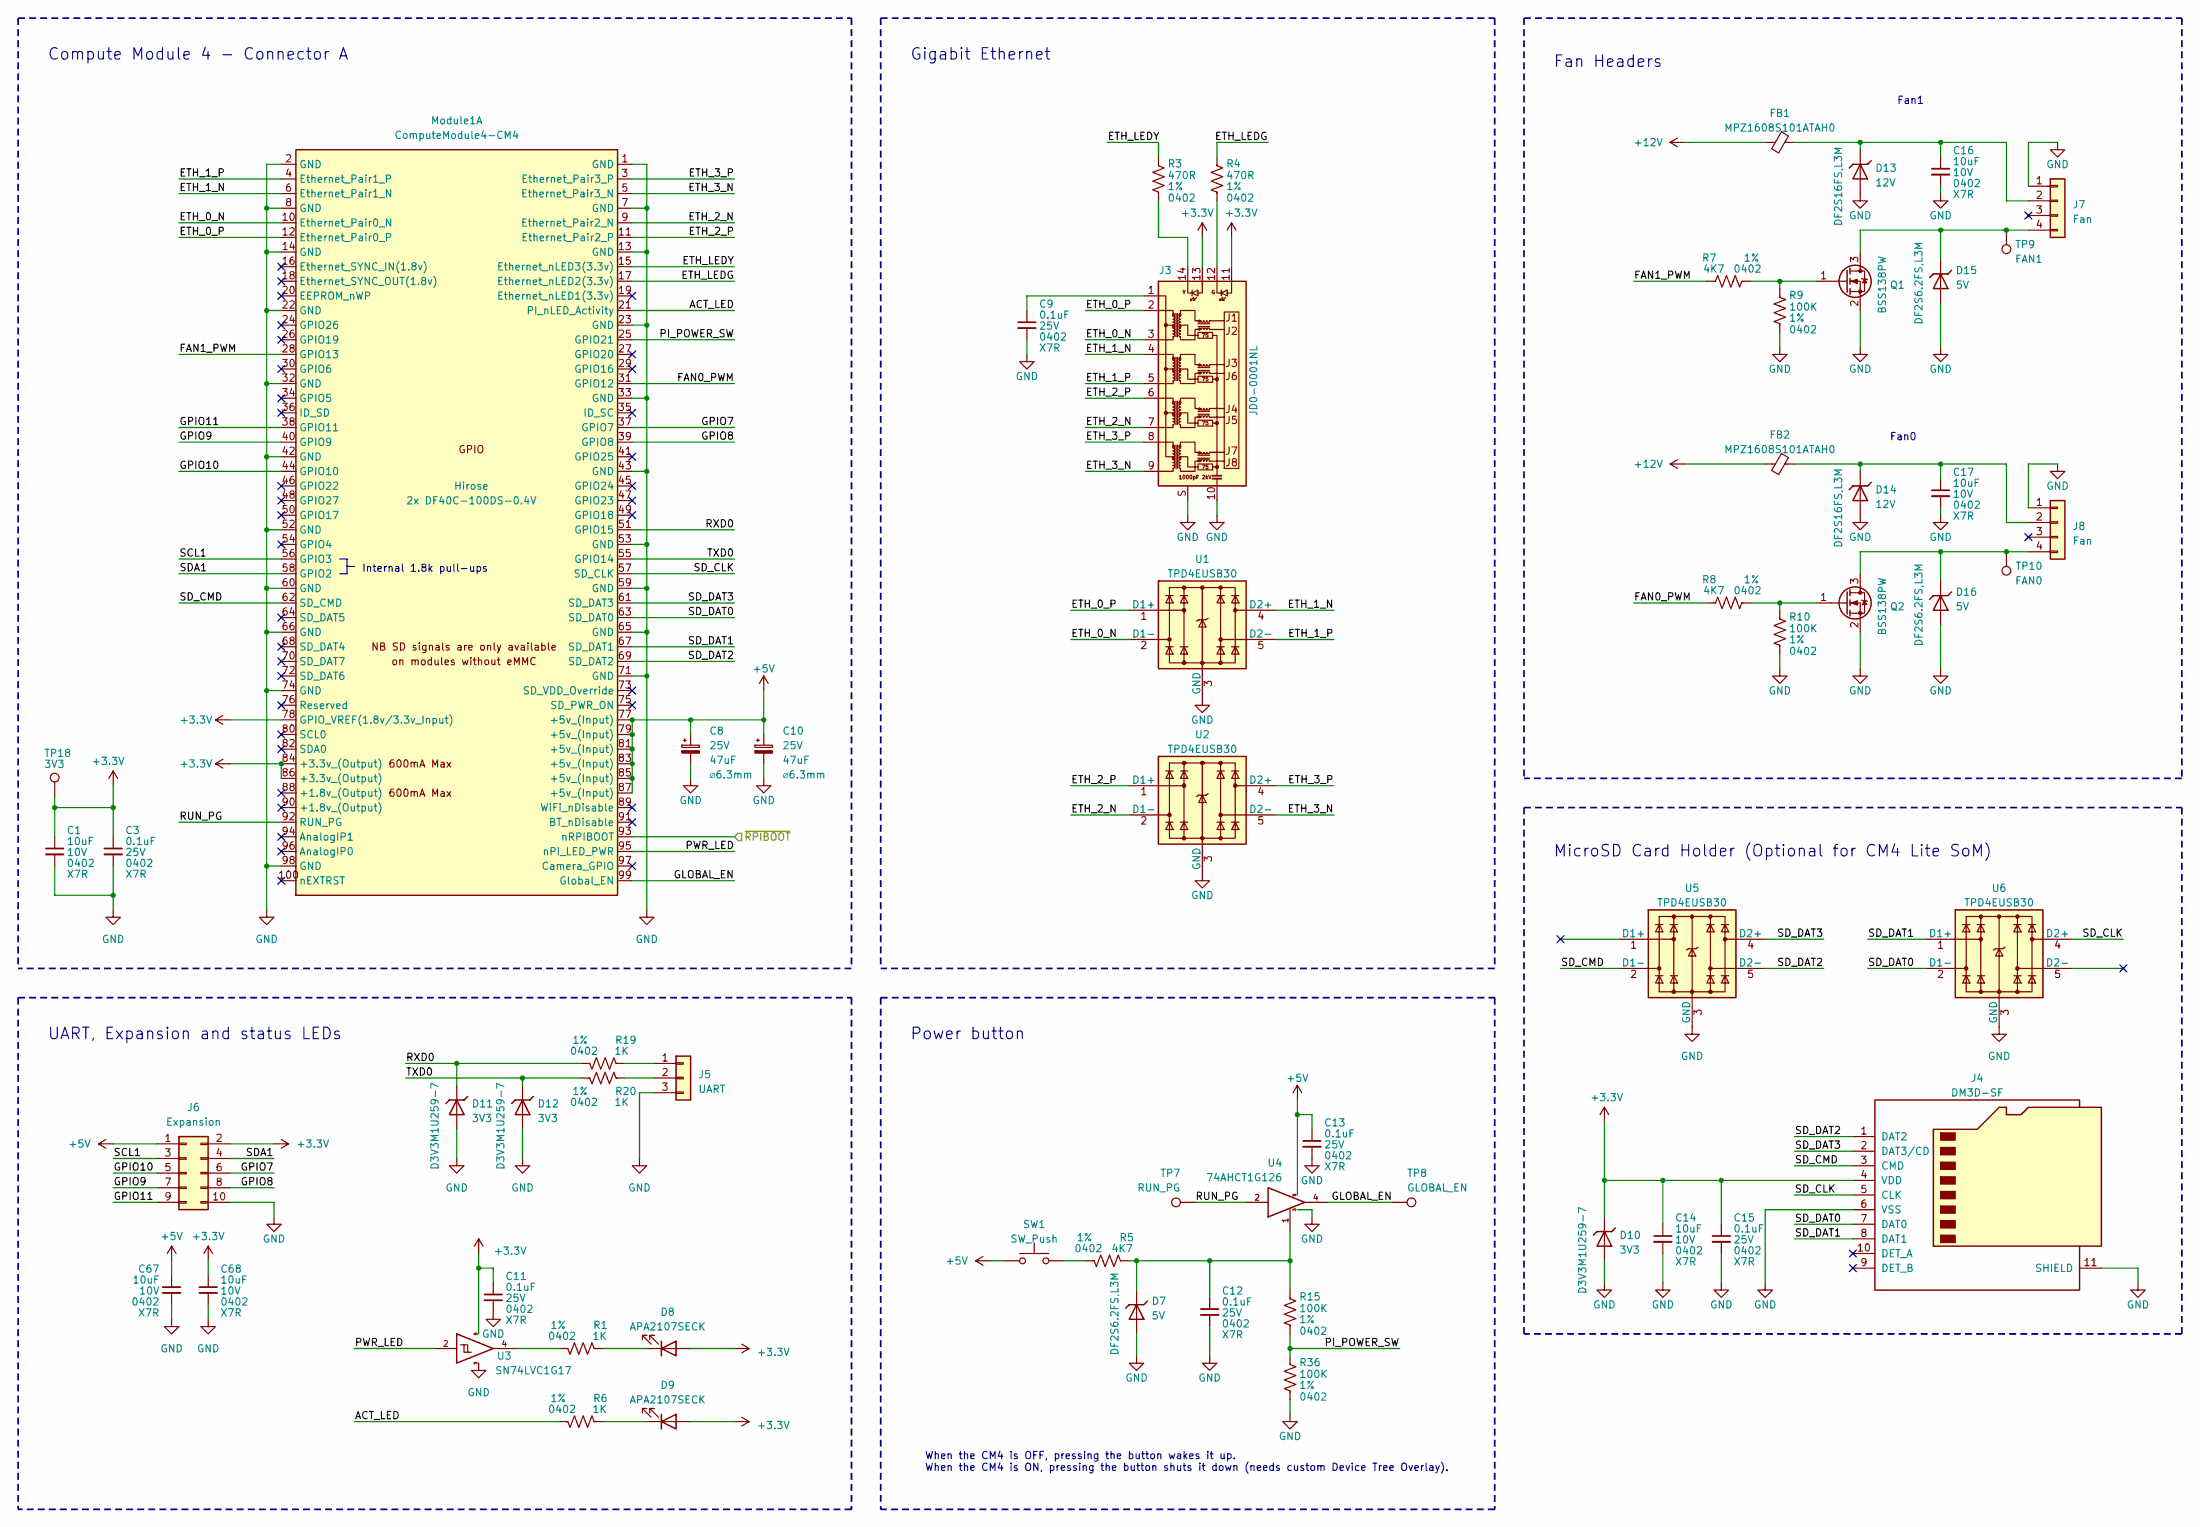
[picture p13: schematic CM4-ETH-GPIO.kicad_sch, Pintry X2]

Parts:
C1, C14, C16, C17, C67, C68: 10uF; C_0402_1005Metric; Voltage Rating 10V
C3, C9, C11, C12, C13, C15: 0.1uF; C_0402_1005Metric; Voltage Rating 25V
C8, C10: 865080443007; CP_Elec_6.3x5.4; Voltage 25V; Part Number 865080443007
D7, D15, D16: DF2S6.2FS,L3M; D_SOD-923; Part Number DF2S6.2FS,L3M
D8, D9: APA2107SECK; PartNumber APA2107SECK/J4-PRV
D10, D11, D12: D3V3M1U259-7; D_SOD-923; Part Number D3V3M1U2S9-7
D13, D14: DF2S16FS,L3M; D_SOD-923; Part Number DF2S16FS,L3M
FB1, FB2: MPZ1608S101ATAH0; L_0603_1608Metric; Part Number MPZ1608S101ATAH0
J3: JD0-0001NL; Pulse-JD0-0001NL-0-0-MFG; Part Number JD0-0001NL
J4: DM3D-SF; microSD_HC_Hirose_DM3D-SF; Part Number DM3D-SF
J5: UART; PinHeader_1x03_P2.54mm_Vertical; Part Number PH1-03-UA
J6: Expansion; PinHeader_2x05_P2.54mm_Vertical; Part Number 2PH2-10-UA
J7, J8: Fan; Molex_KK-254_AE-6410-04A_1x04_P2.54mm_Vertical; Part Number 47053-1000
Module1: ComputeModule4-CM4; Raspberry-Pi-4-Compute-Module; Part Number 2x DF40C-100DS-0.4V
Q1, Q2: BSS138PW; SOT-323_SC-70; Part Number BSS138PW,115
R1, R6, R19, R20: 1K; R_0402_1005Metric; Tolerance 1%
R3, R4: 470R; R_0402_1005Metric; Tolerance 1%
R5, R7, R8: 4K7; R_0402_1005Metric; Tolerance 1%
R9, R10, R15, R36: 100K; R_0402_1005Metric; Tolerance 1%
SW1: SW_Push; SW_Tactile_SPST_Angled_PTS645Vx58-2LFS; Part Number 1-1825027-4
TP7: RUN_PG; TestPoint_Pad_D1.0mm
TP8: GLOBAL_EN; TestPoint_Pad_D1.0mm
TP9: FAN1; TestPoint_Pad_D1.0mm
TP10: FAN0; TestPoint_Pad_D1.0mm
TP18: 3V3; TestPoint_Pad_D1.0mm
U1, U2, U5, U6: TPD4EUSB30; USON-10_2.5x1.0mm_P0.5mm; Part Number TPD4EUSB30DQAR
U3: SN74LVC1G17; SOT-23-5; Part Number SN74LVC1G17DBVR
U4: 74AHCT1G126; SOT-353_SC-70-5; Part Number 74AHCT1G126SE-7

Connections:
+3V3: C1.1, C3.1, C11.1, C14.1, C15.1, C68.1, D8.2 (A), D9.2 (A), D10.1 (K), J3.11, J3.13, J4.4 (VDD), J6.2, Module1.78 (GPIO_VREF(1.8v/3.3v_Input)), Module1.84 (+3.3v_(Output)), Module1.86 (+3.3v_(Output)), TP18.1, U3.5 (VCC); also elsewhere on the board
+5V: C8.1, C10.1, C13.1, C67.1, J6.1, Module1.77 (+5v_(Input)), Module1.79 (+5v_(Input)), Module1.81 (+5v_(Input)), Module1.83 (+5v_(Input)), Module1.85 (+5v_(Input)), Module1.87 (+5v_(Input)), SW1.1, U4.5 (VCC); also elsewhere on the board
+12V: FB1.2, FB2.2; also elsewhere on the board
/CM4-ETH-GPIO/ACT_LED: Module1.21 (PI_nLED_Activity), R6.2
/CM4-ETH-GPIO/ETH_0_N: J3.3, Module1.10 (Ethernet_Pair0_N), U1.2 (D1-), U1.9
/CM4-ETH-GPIO/ETH_0_P: J3.2, Module1.12 (Ethernet_Pair0_P), U1.1 (D1+), U1.10
/CM4-ETH-GPIO/ETH_1_N: J3.4, Module1.6 (Ethernet_Pair1_N), U1.4 (D2+), U1.7
/CM4-ETH-GPIO/ETH_1_P: J3.5, Module1.4 (Ethernet_Pair1_P), U1.5 (D2-), U1.6
/CM4-ETH-GPIO/ETH_2_N: J3.7, Module1.9 (Ethernet_Pair2_N), U2.2 (D1-), U2.9
/CM4-ETH-GPIO/ETH_2_P: J3.6, Module1.11 (Ethernet_Pair2_P), U2.1 (D1+), U2.10
/CM4-ETH-GPIO/ETH_3_N: J3.9, Module1.5 (Ethernet_Pair3_N), U2.5 (D2-), U2.6
/CM4-ETH-GPIO/ETH_3_P: J3.8, Module1.3 (Ethernet_Pair3_P), U2.4 (D2+), U2.7
/CM4-ETH-GPIO/ETH_LEDG: Module1.17 (Ethernet_nLED2(3.3v)), R4.1
/CM4-ETH-GPIO/ETH_LEDY: Module1.15 (Ethernet_nLED3(3.3v)), R3.1
/CM4-ETH-GPIO/FAN0_PWM: Module1.31 (GPIO12), R8.1
/CM4-ETH-GPIO/FAN1_PWM: Module1.28 (GPIO13), R7.1
/CM4-ETH-GPIO/GLOBAL_EN: Module1.99 (Global_EN), TP8.1, U4.4
/CM4-ETH-GPIO/GPIO7: J6.6, Module1.37 (GPIO7)
/CM4-ETH-GPIO/GPIO8: J6.8, Module1.39 (GPIO8)
/CM4-ETH-GPIO/GPIO9: J6.7, Module1.40 (GPIO9)
/CM4-ETH-GPIO/GPIO10: J6.5, Module1.44 (GPIO10)
/CM4-ETH-GPIO/GPIO11: J6.9, Module1.38 (GPIO11)
/CM4-ETH-GPIO/PI_POWER_SW: Module1.25 (GPIO21), R15.2, R36.1
/CM4-ETH-GPIO/PWR_LED: Module1.95 (nPI_LED_PWR), U3.2
/CM4-ETH-GPIO/RUN_PG: Module1.92 (RUN_PG), TP7.1, U4.2
/CM4-ETH-GPIO/RXD0: D11.1 (K), Module1.51 (GPIO15), R19.2
/CM4-ETH-GPIO/SCL1: J6.3, Module1.56 (GPIO3)
/CM4-ETH-GPIO/SDA1: J6.4, Module1.58 (GPIO2)
/CM4-ETH-GPIO/SD_CLK: J4.5 (CLK), Module1.57 (SD_CLK), U6.4 (D2+), U6.7
/CM4-ETH-GPIO/SD_CMD: J4.3 (CMD), Module1.62 (SD_CMD), U5.2 (D1-), U5.9
/CM4-ETH-GPIO/SD_DAT0: J4.7 (DAT0), Module1.63 (SD_DAT0), U6.2 (D1-), U6.9
/CM4-ETH-GPIO/SD_DAT1: J4.8 (DAT1), Module1.67 (SD_DAT1), U6.1 (D1+), U6.10
/CM4-ETH-GPIO/SD_DAT2: J4.1 (DAT2), Module1.69 (SD_DAT2), U5.5 (D2-), U5.6
/CM4-ETH-GPIO/SD_DAT3: J4.2 (DAT3/CD), Module1.61 (SD_DAT3), U5.4 (D2+), U5.7
/CM4-ETH-GPIO/TXD0: D12.1 (K), Module1.55 (GPIO14), R20.2
/CM4-ETH-GPIO/~RPIBOOT: Module1.93 (nRPIBOOT); also elsewhere on the board
GND: C1.2, C3.2, C8.2, C9.2, C10.2, C11.2, C12.2, C13.2, C14.2, C15.2, C16.2, C17.2, C67.2, C68.2, D7.2 (A), D10.2 (A), D11.2 (A), D12.2 (A), D13.2 (A), D14.2 (A), D15.2 (A), D16.2 (A), J3.10, J3.S, J4.6 (VSS), J4.11 (SHIELD), J5.3, J6.10, J7.1, J8.1, Module1.1 (GND), Module1.2 (GND), Module1.7 (GND), Module1.8 (GND), Module1.13 (GND), Module1.14 (GND), Module1.22 (GND), Module1.23 (GND), Module1.32 (GND), Module1.33 (GND), Module1.42 (GND), Module1.43 (GND), Module1.52 (GND), Module1.53 (GND), Module1.59 (GND), Module1.60 (GND), Module1.65 (GND), Module1.66 (GND), Module1.71 (GND), Module1.74 (GND), Module1.98 (GND), Q1.2 (S), Q2.2 (S), R9.2, R10.2, R36.2, U1.3 (GND), U1.8 (GND), U2.3 (GND), U2.8 (GND), U3.3 (GND), U4.3 (GND), U5.3 (GND), U5.8 (GND), U6.3 (GND), U6.8 (GND); also elsewhere on the board
unnamed: C9.1, J3.1
unnamed: C12.1, D7.1 (K), R5.1, R15.1, U4.1
unnamed: C16.1, D13.1 (K), FB1.1, J7.2
unnamed: C17.1, D14.1 (K), FB2.1, J8.2
unnamed: D8.1 (K), R1.1
unnamed: D9.1 (K), R6.1
unnamed: D15.1 (K), J7.4, Q1.3 (D), TP9.1
unnamed: D16.1 (K), J8.4, Q2.3 (D), TP10.1
unnamed: J3.12, R4.2
unnamed: J3.14, R3.2
unnamed: J5.1, R19.1
unnamed: J5.2, R20.1
unnamed: Q1.1 (G), R7.2, R9.1
unnamed: Q2.1 (G), R8.2, R10.1
unnamed: R1.2, U3.4
unnamed: R5.2, SW1.2

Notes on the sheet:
Gigabit Ethernet
Internal 1.8k pull-ups
When the CM4 is OFF, pressing the button wakes it up. When the CM4 is ON, pressing the button shuts it down (needs custom Device Tree Overlay).
UART, Expansion and status LEDs
MicroSD Card Holder (Optional for CM4 Lite SoM)
Fan1
Fan0
Fan Headers
Power button
Compute Module 4 - Connector A

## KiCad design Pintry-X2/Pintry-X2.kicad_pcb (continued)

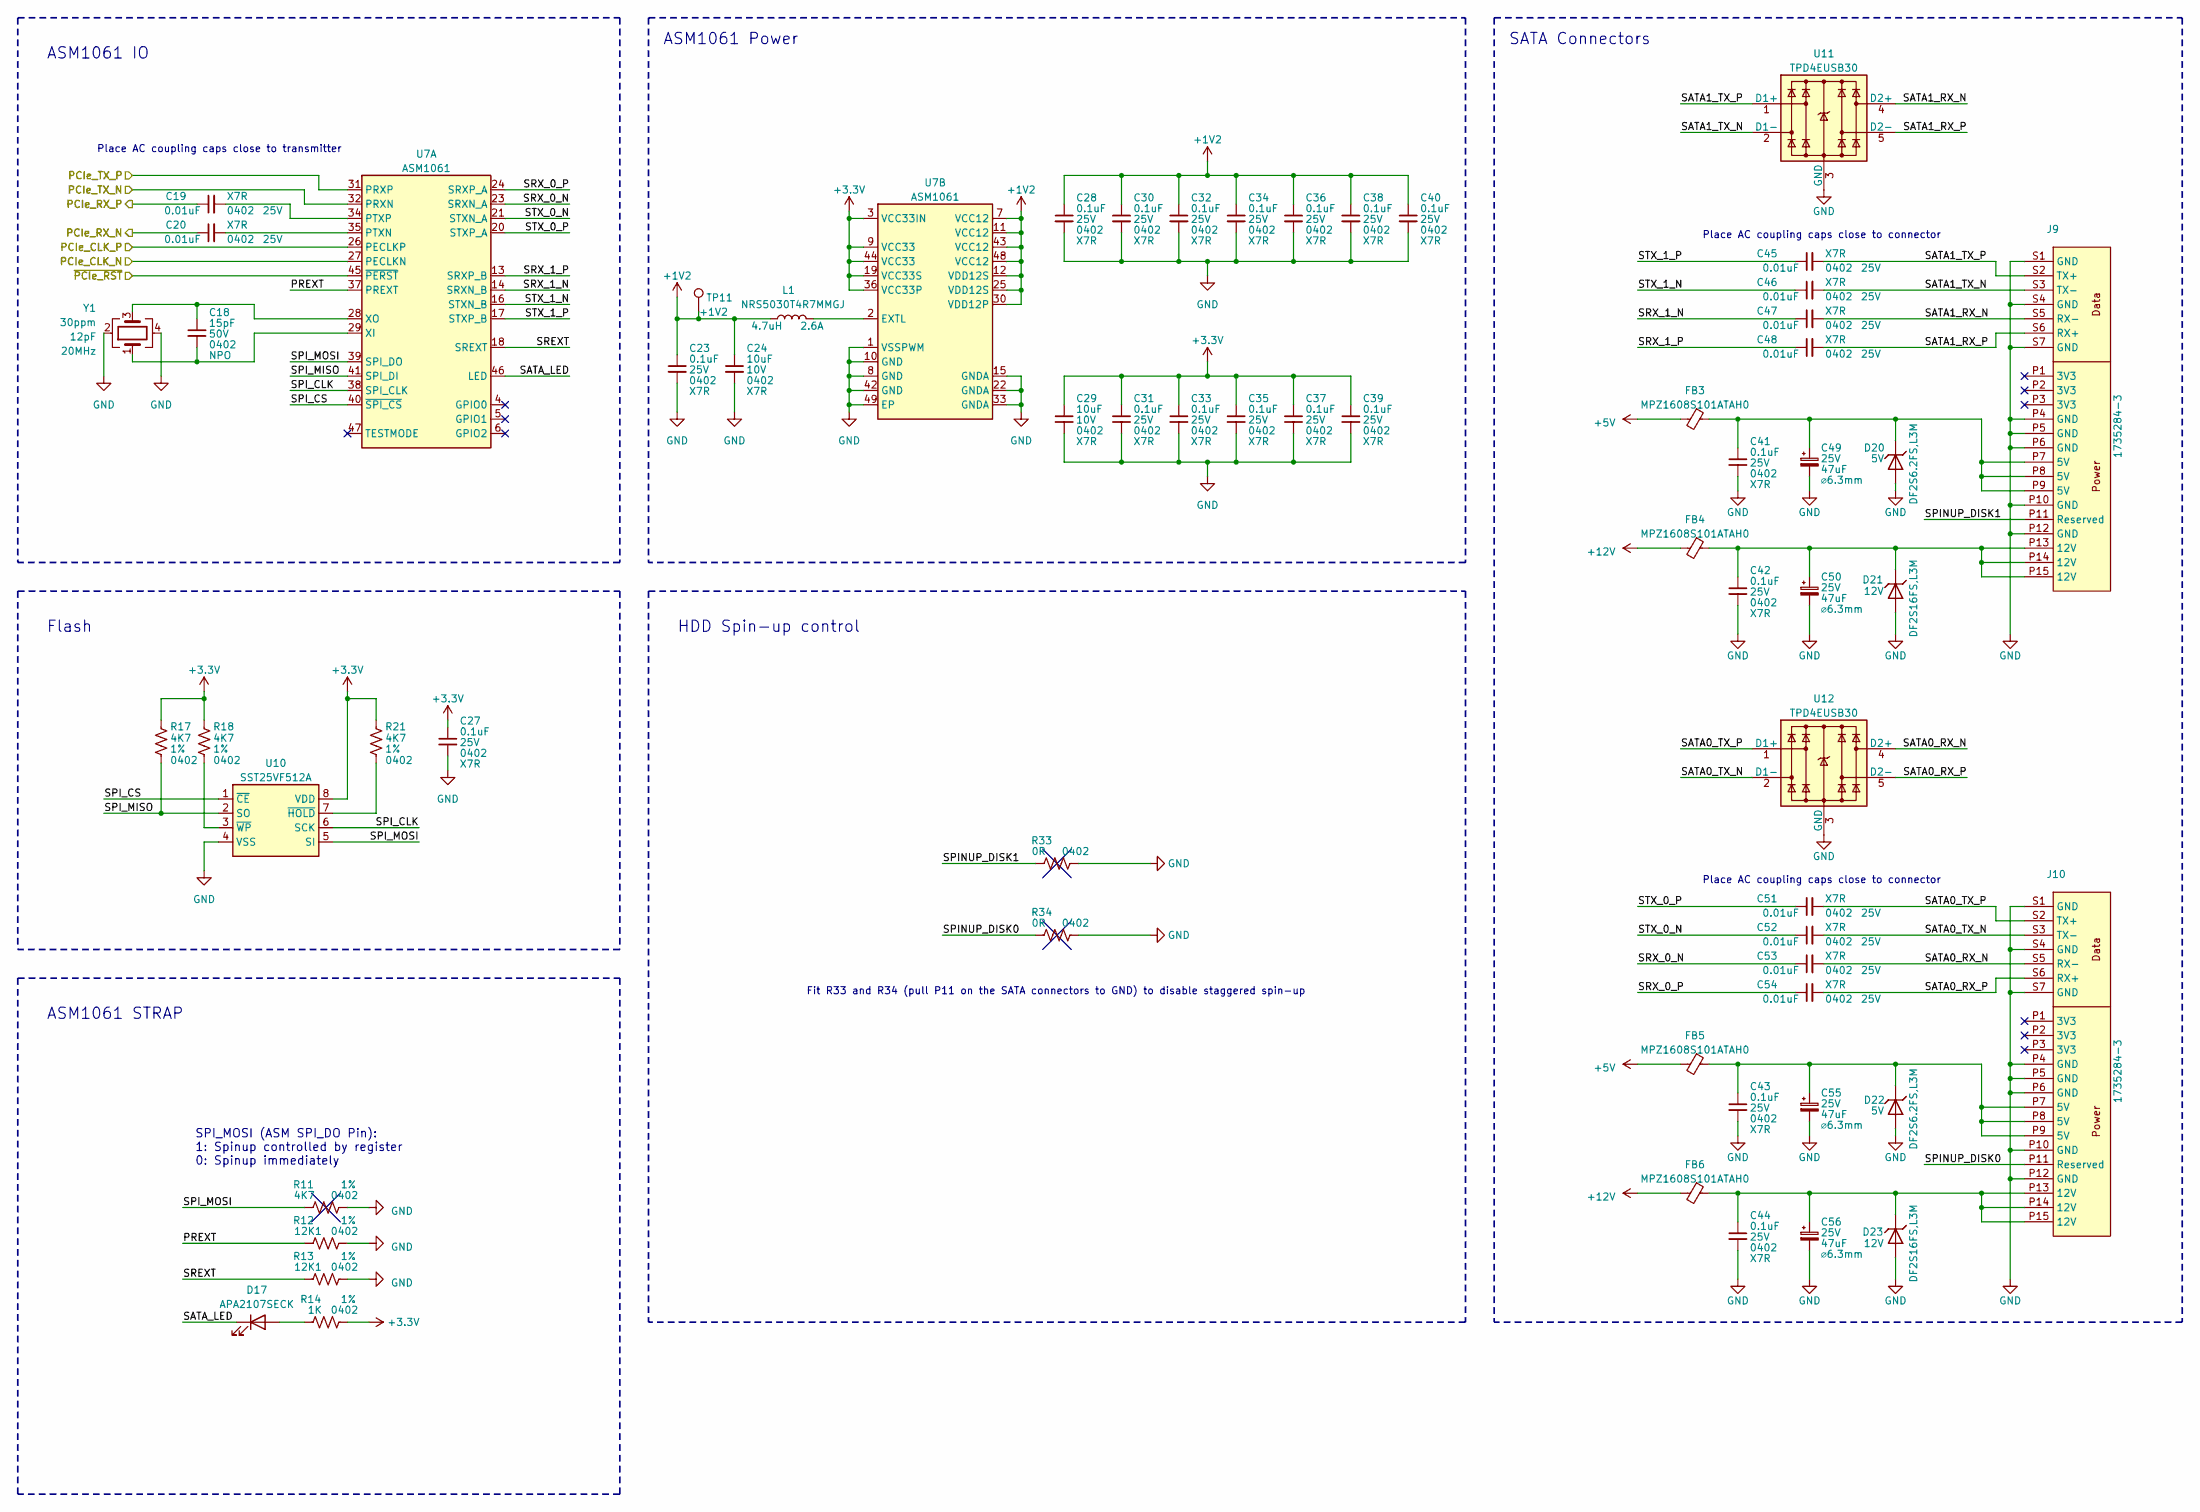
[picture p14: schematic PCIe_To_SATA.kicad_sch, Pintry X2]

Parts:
C18: 15pF; C_0402_1005Metric; Voltage Rating 50V
C19, C20, C45, C46, C47, C48, C51, C52, C53, C54: 0.01uF; C_0402_1005Metric; Voltage Rating 25V
C23, C27, C28, C30, C31, C32, C33, C34, C35, C36, C37, C38, C39, C40, C41, C42, C43, C44: 0.1uF; C_0402_1005Metric; Voltage Rating 25V
C24, C29: 10uF; C_0402_1005Metric; Voltage Rating 10V
C49, C50, C55, C56: 865080443007; CP_Elec_6.3x5.4; Voltage 25V; Part Number 865080443007
D17: APA2107SECK; PartNumber APA2107SECK/J4-PRV
D20, D22: DF2S6.2FS,L3M; D_SOD-923; Part Number DF2S6.2FS,L3M
D21, D23: DF2S16FS,L3M; D_SOD-923; Part Number DF2S16FS,L3M
FB3, FB4, FB5, FB6: MPZ1608S101ATAH0; L_0603_1608Metric; Part Number MPZ1608S101ATAH0
J9, J10: 1735284-3; TE_1735284-3; Part Number 1735284-3
L1: NRS5030T4R7MMGJ; L_Taiyo-Yuden_NR-50xx; Current Rating 2.6A; Part Number NRS5030T4R7MMGJ
R11, R17, R18, R21: 4K7; R_0402_1005Metric; Tolerance 1%
R12, R13: 12K1; R_0402_1005Metric; Tolerance 1%
R14: 1K; R_0402_1005Metric; Tolerance 1%
R33, R34: 0R; R_0402_1005Metric; Tolerance 1%
TP11: +1V2; TestPoint_Pad_D1.0mm
U7: ASM1061; QFN-48-1EP_7x7mm_P0.5mm_EP4.025x4.025mm
U10: SST25VF512A; SOIC-8_3.9x4.9mm_P1.27mm; Part Number SST25VF512A-33-4I-SAE-T
U11, U12: TPD4EUSB30; USON-10_2.5x1.0mm_P0.5mm; Part Number TPD4EUSB30DQAR
Y1: ECS-200-12-33-AGN-TR; Crystal_SMD_3225-4Pin_3.2x2.5mm; Part Number ECS-200-12-33-AGN-TR

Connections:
+1V2: C23.1, C24.1, C28.1, C30.1, C32.1, C34.1, C36.1, C38.1, C40.1, L1.1, TP11.1, U7.7 (VCC12), U7.11 (VCC12), U7.12 (VDD12S), U7.25 (VDD12S), U7.30 (VDD12P), U7.43 (VCC12), U7.48 (VCC12)
+3V3: C27.1, C29.1, C31.1, C33.1, C35.1, C37.1, C39.1, R14.2, R17.1, R18.1, R21.1, U7.3 (VCC33IN), U7.9 (VCC33), U7.19 (VCC33S), U7.36 (VCC33P), U7.44 (VCC33), U10.8 (VDD); also elsewhere on the board
+5V: FB3.2, FB5.2; also elsewhere on the board
+12V: FB4.2, FB6.2; also elsewhere on the board
/CM4-USB-PCIe/PCIe_CLK_N: U7.27 (PECLKN); also elsewhere on the board
/CM4-USB-PCIe/PCIe_CLK_P: U7.26 (PECLKP); also elsewhere on the board
/CM4-USB-PCIe/PCIe_RX_N: C20.1; also elsewhere on the board
/CM4-USB-PCIe/PCIe_RX_P: C19.1; also elsewhere on the board
/CM4-USB-PCIe/PCIe_TX_N: U7.32 (PRXN); also elsewhere on the board
/CM4-USB-PCIe/PCIe_TX_P: U7.31 (PRXP); also elsewhere on the board
/CM4-USB-PCIe/~PCIe_RST: U7.45 (~PERST); also elsewhere on the board
/PCIe to SATA/PREXT: R12.1, U7.37 (PREXT)
/PCIe to SATA/SATA0_RX_N: C53.2, J10.S5 (RX-), U12.4 (D2+), U12.7
/PCIe to SATA/SATA0_RX_P: C54.2, J10.S6 (RX+), U12.5 (D2-), U12.6
/PCIe to SATA/SATA0_TX_N: C52.2, J10.S3 (TX-), U12.2 (D1-), U12.9
/PCIe to SATA/SATA0_TX_P: C51.2, J10.S2 (TX+), U12.1 (D1+), U12.10
/PCIe to SATA/SATA1_RX_N: C47.2, J9.S5 (RX-), U11.4 (D2+), U11.7
/PCIe to SATA/SATA1_RX_P: C48.2, J9.S6 (RX+), U11.5 (D2-), U11.6
/PCIe to SATA/SATA1_TX_N: C46.2, J9.S3 (TX-), U11.2 (D1-), U11.9
/PCIe to SATA/SATA1_TX_P: C45.2, J9.S2 (TX+), U11.1 (D1+), U11.10
/PCIe to SATA/SATA_LED: D17.1 (K), U7.46 (LED)
/PCIe to SATA/SPINUP_DISK0: J10.P11 (Reserved), R34.1
/PCIe to SATA/SPINUP_DISK1: J9.P11 (Reserved), R33.1
/PCIe to SATA/SPI_CLK: U7.38 (SPI_CLK), U10.6 (SCK)
/PCIe to SATA/SPI_CS: U7.40 (~SPI_CS), U10.1 (~CE)
/PCIe to SATA/SPI_MISO: R17.2, U7.41 (SPI_DI), U10.2 (SO)
/PCIe to SATA/SPI_MOSI: R11.1, U7.39 (SPI_DO), U10.5 (SI)
/PCIe to SATA/SREXT: R13.1, U7.18 (SREXT)
/PCIe to SATA/SRX_0_N: C53.1, U7.23 (SRXN_A)
/PCIe to SATA/SRX_0_P: C54.1, U7.24 (SRXP_A)
/PCIe to SATA/SRX_1_N: C47.1, U7.14 (SRXN_B)
/PCIe to SATA/SRX_1_P: C48.1, U7.13 (SRXP_B)
/PCIe to SATA/STX_0_N: C52.1, U7.21 (STXN_A)
/PCIe to SATA/STX_0_P: C51.1, U7.20 (STXP_A)
/PCIe to SATA/STX_1_N: C46.1, U7.16 (STXN_B)
/PCIe to SATA/STX_1_P: C45.1, U7.17 (STXP_B)
GND: C23.2, C24.2, C27.2, C28.2, C29.2, C30.2, C31.2, C32.2, C33.2, C34.2, C35.2, C36.2, C37.2, C38.2, C39.2, C40.2, C41.2, C42.2, C43.2, C44.2, C49.2, C50.2, C55.2, C56.2, D20.2 (A), D21.2 (A), D22.2 (A), D23.2 (A), J9.P4 (GND), J9.P5 (GND), J9.P6 (GND), J9.P10 (GND), J9.P12 (GND), J9.S1 (GND), J9.S4 (GND), J9.S7 (GND), J10.P4 (GND), J10.P5 (GND), J10.P6 (GND), J10.P10 (GND), J10.P12 (GND), J10.S1 (GND), J10.S4 (GND), J10.S7 (GND), R11.2, R12.2, R13.2, R33.2, R34.2, U7.1 (VSSPWM), U7.8 (GND), U7.10 (GND), U7.15 (GNDA), U7.22 (GNDA), U7.33 (GNDA), U7.42 (GND), U7.49 (EP), U10.4 (VSS), U11.3 (GND), U11.8 (GND), U12.3 (GND), U12.8 (GND), Y1.2, Y1.4; also elsewhere on the board
unnamed: C18.1, U7.28 (XO), Y1.3
unnamed: C18.2, U7.29 (XI), Y1.1
unnamed: C19.2, U7.34 (PTXP)
unnamed: C20.2, U7.35 (PTXN)
unnamed: C41.1, C49.1, D20.1 (K), FB3.1, J9.P7 (5V), J9.P8 (5V), J9.P9 (5V)
unnamed: C42.1, C50.1, D21.1 (K), FB4.1, J9.P13 (12V), J9.P14 (12V), J9.P15 (12V)
unnamed: C43.1, C55.1, D22.1 (K), FB5.1, J10.P7 (5V), J10.P8 (5V), J10.P9 (5V)
unnamed: C44.1, C56.1, D23.1 (K), FB6.1, J10.P13 (12V), J10.P14 (12V), J10.P15 (12V)
unnamed: D17.2 (A), R14.1
unnamed: L1.2, U7.2 (EXTL)
unnamed: R18.2, U10.3 (~WP)
unnamed: R21.2, U10.7 (~HOLD)

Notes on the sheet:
SATA Connectors
ASM1061 STRAP
ASM1061 IO
Flash
Place AC coupling caps close to transmitter
SPI_MOSI (ASM SPI_DO Pin): 1: Spinup controlled by register 0: Spinup immediately
HDD Spin-up control
Place AC coupling caps close to connector
Fit R33 and R34 (pull P11 on the SATA connectors to GND) to disable staggered spin-up
ASM1061 Power

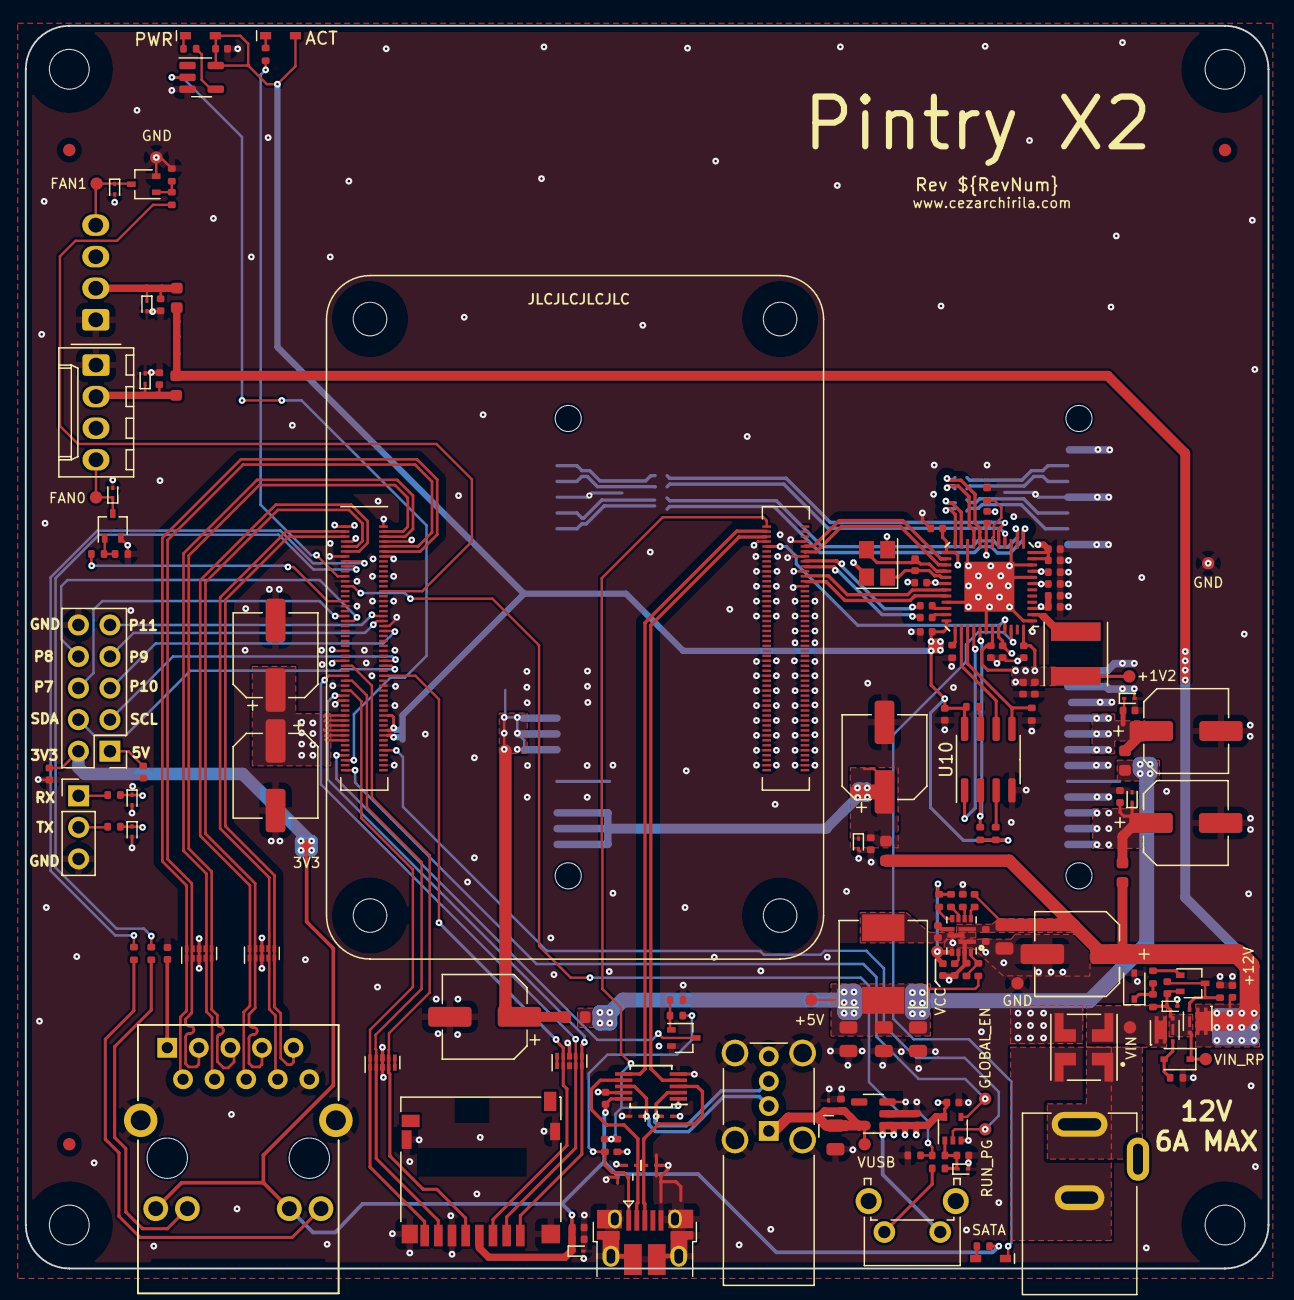
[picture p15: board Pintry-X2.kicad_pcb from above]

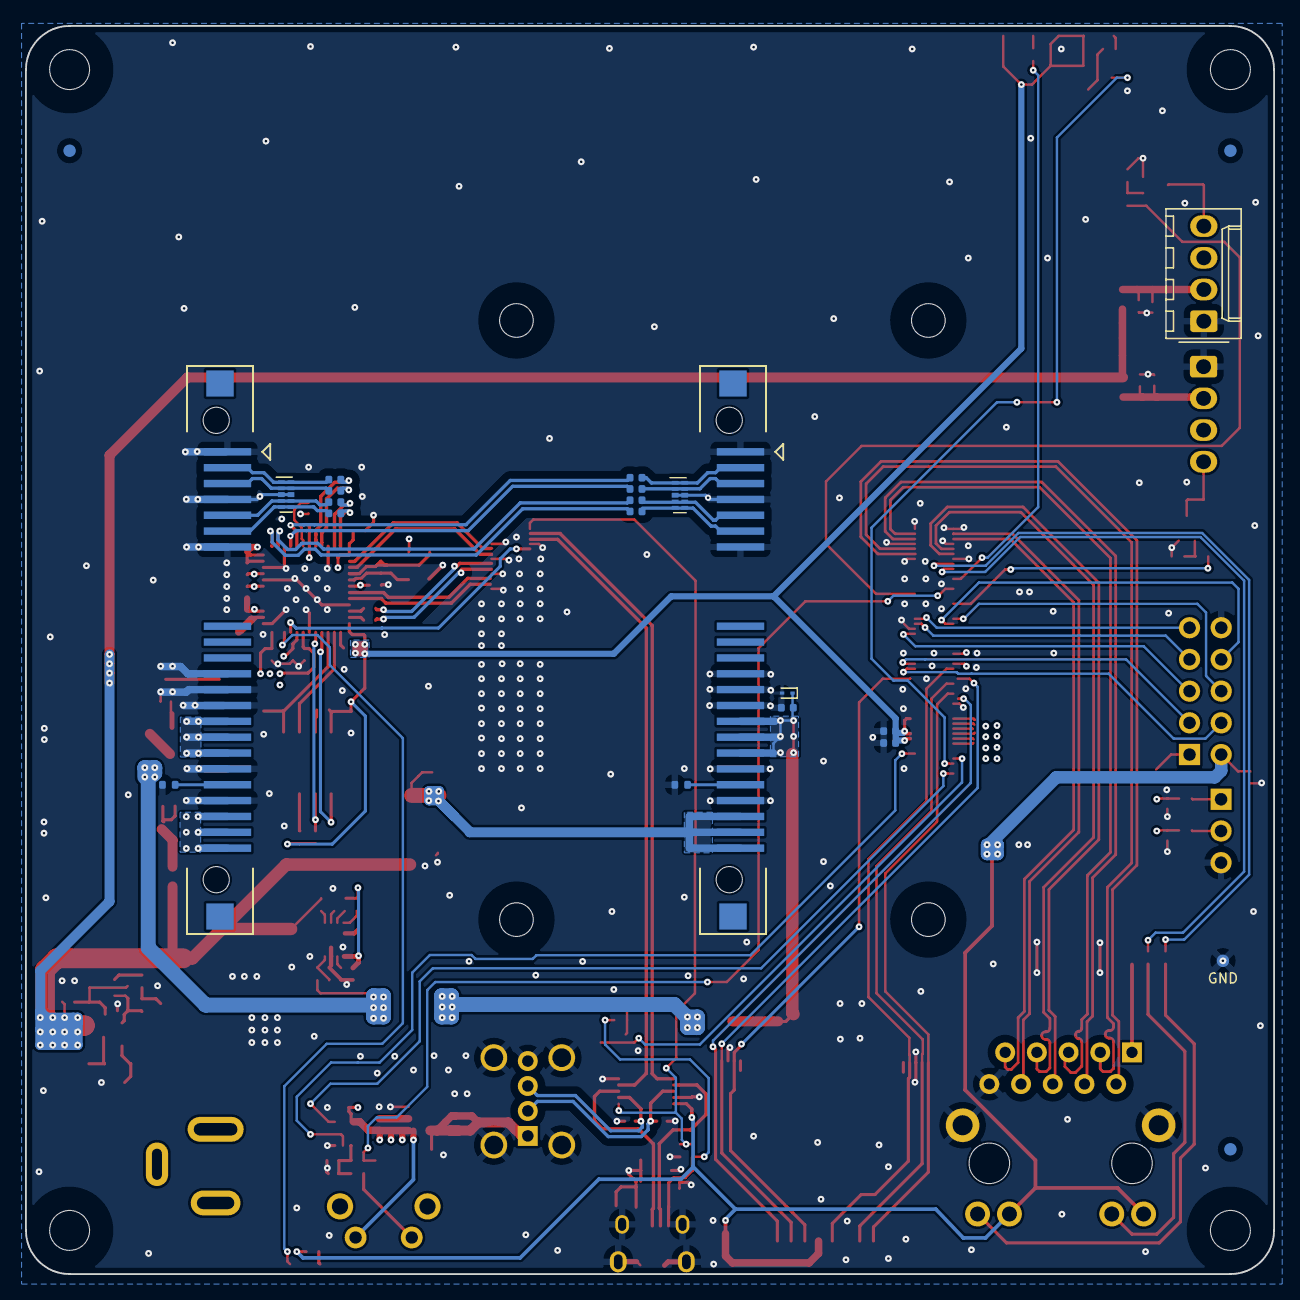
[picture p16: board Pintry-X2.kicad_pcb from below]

Board: 4 copper layers, 100.0 x 100.0 mm, 193 parts (23 on the bottom side), 125 nets.

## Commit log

2021-05-30 Initialise Project
    [CM4.kicad_sch, Pintry-X2.kicad_pcb, Pintry-X2.kicad_sch]
2021-06-25 Bunch of shit done, probably should commit
    [CM4-A.kicad_sch, CM4-B.kicad_sch, CM4-ETH-GPIO.kicad_sch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]
2021-06-26 Cleaned up schematic
    [CM4-ETH-GPIO.kicad_sch, CM4-USB-PCIe.kicad_sch, PCIe_To_SATA.kicad_sch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]
2021-07-04 Finished Shematic. Starting PCB
    [CM4-ETH-GPIO.kicad_sch, CM4-USB-PCIe.kicad_sch, PCIe_To_SATA.kicad_sch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]
2021-10-20 PCB Routing Complete - needs review
    [CM4-ETH-GPIO.kicad_sch, CM4-USB-PCIe.kicad_sch, PCIe_To_SATA.kicad_sch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]
2021-10-23 Final touches and generate Gerbers to be sent to fab
    [CM4-USB-PCIe.kicad_sch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]
2021-11-27 Updated to Rev 1.1. Added interactive HTML
    [PCIe_To_SATA.kicad_sch, Pintry-X2.kicad_sch]
2021-11-27 Update path for Interactive BOM
2021-11-28 Fixed ON/OFF Button
    [CM4-ETH-GPIO.kicad_sch, CM4-USB-PCIe.kicad_sch, Pintry-X2.kicad_sch]
2021-11-28 Remove OutputJob
    [CM4-A.kicad_sch, CM4-B.kicad_sch, CM4-ETH-GPIO.kicad_sch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]
2021-12-20 Moved ethernet connector so that it sticks out a bit
    [CM4-ETH-GPIO.kicad_sch]
2021-12-20 Improved DRC routing. Removed DTO files.
    [Pintry-X2.kicad_pcb]
2021-12-30 Release version 1.1
    [Bottom.stl, CM4-ETH-GPIO.kicad_sch, CM4-USB-PCIe.kicad_sch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]
